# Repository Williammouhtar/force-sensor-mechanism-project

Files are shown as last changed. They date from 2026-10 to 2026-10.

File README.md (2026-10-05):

this project is meant to introduce flexure mechanisms through a force sensor project.
This project focuses mainly on translating user specifications into mechanical requirements in order to create a product that suits the user best.
such force sensors are used in industry by companies such as Hexagon for surface measurements as well as to recreate mechanical products into digital CAD
designs by taking multiple measurements on the entirety of the surface desired.

A detailed report is available in the Force-sensor-Rapport.pdf file.

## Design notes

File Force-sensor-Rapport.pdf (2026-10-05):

# Conception de Mécanisme : rapport

Marc Abou Jaoude, Oliver Abela, William El Mouhtar, Ziad Kriedieh,

## Tarek Hamad

### Projet de conception de mecanisme

Mai 2025

## Remerciements

Nous sommes reconnaissants envers Prof. Simon Henein pour avoir initialement mis en place ce projet et pour son soutien tout au long de son développement.

Nous tenons également à exprimer notre gratitude envers notre assistant principal, Prof. Florent Cosandier, dont le soutien continu a été d’une aide précieuse tout au long de ce projet.

De plus, nous souhaitons adresser nos remerciements les plus chaleureux à notre assistant secondaire, Alexandre Dao, pour ses conseils tout au long du semestre.

## Table des matières

1 Introduction | 3
2 Conception générale | 4
2.2 Schéma cinématique du corps d’épreuve représenté avec des articulations idéales . . . | 7
2.3 Calcul de la mobilité selon la méthode de Grübler et discussion des éventuels hyper-
3 Dimensionnement Détaillé | 8
3.5.1 | Calcul d’erreur pour une accélération en z due à la non-linéarité de l’équilibrage 20
4 Discussion | 24
5 Construction | 24
5.1 Argumentation des choix de construction (procédé d’usinage et assemblages, etc.) . . 24
6 Conclusion | 26
7 Annexes | 26

## 1 Introduction

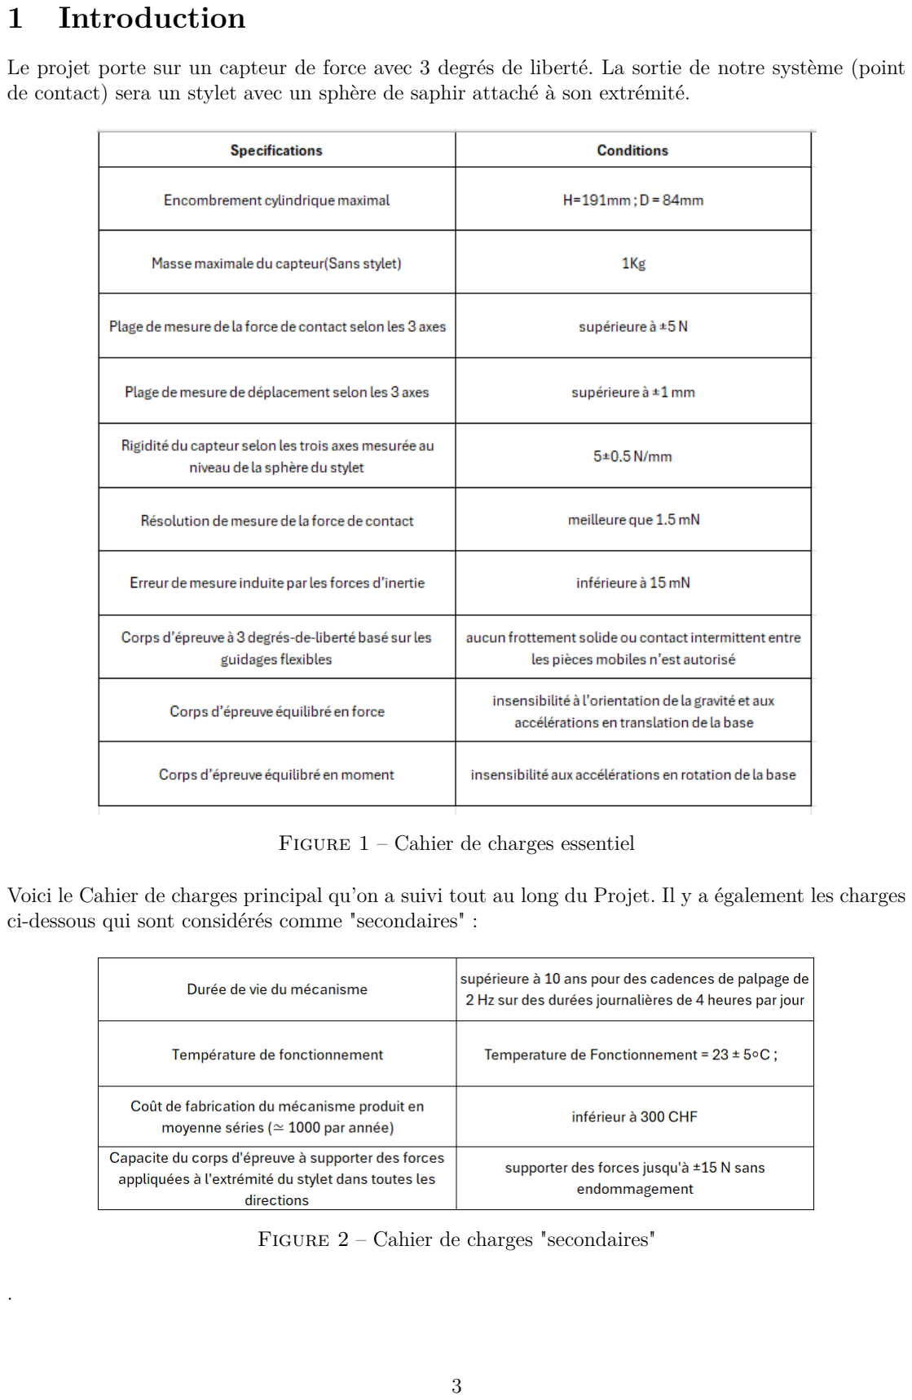
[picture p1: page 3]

Le projet porte sur un capteur de force avec 3 degrés de liberté. La sortie de notre système (point de contact) sera un stylet avec un sphère de saphir attaché à son extrémité.

Figure 1 – Cahier de charges essentiel

Voici le Cahier de charges principal qu’on a suivi tout au long du Projet. Il y a également les charges ci-dessous qui sont considérés comme "secondaires" :

Figure 2 – Cahier de charges "secondaires"

## 2 Conception générale

### 2.1 Explication du principe de fonctionnement

### 2.1.1 Principe de guidage du stylet à 3 degrés-de-liberté

Le système sera dans un cylindre de diamètre D = 84 mm et de hauteur H = 191 mm. Notre stylet aura les trois degrés de libertés suivantes : translations sur l’axe z, translation sur l’axe y et rotation sur l’axe x.

— Translation selon l’axe Z : ce mouvement sera guidé grâce aux deux lames de guidage L3 des deux côtés.
— Translation selon l’axe Y : ce mouvement sera guidé grâce aux quatre lames de base L1. Vu qu’on travaille sur de petits mouvements, on peut assumer que le mouvement selon l’axe de translation Y sera purement translationnel (donc on omet le mouvement parasite «Fp» de rotation).
— Rotation selon l’axe ry : ce mouvement sera guidé grâce aux deux lames de guidage L3 des deux côtés.

### 2.1.2 Principes d’équilibrage en force et en moment

Équilibrage en Force :

Le but fondamental de l’équilibrage en force est d’assurer l’insensibilité du système aux accélérations linéaires ne provenant pas d’une force appliquée sur le stylet. Par exemple, le simple fait de secouer le cylindre sur l’axe Z ne doit pas engendre la translation du stylet et donc du système ; Seul l’application d’une force sur ce dernier doit pouvoir engendrer un tel mouvement. Dans notre cas, on devra alors élaborer un système d’équilibrage en force sur les axes Z et Y.

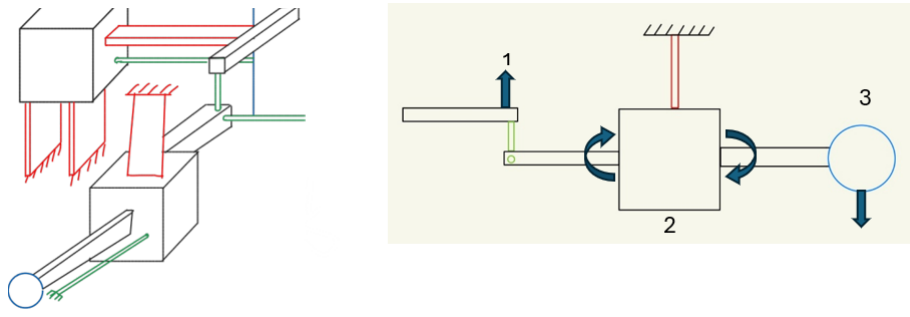
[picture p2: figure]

Figure 3 – Photo agrandie du systeme d’equilibrage en Force"

Considérons une force appliquée sur le stylet suivant l’axe Z. Cela va engendrer les étapes suivantes :

— 1- Translation de la tige t1.
— 2- rotation du bloc grâce à la lame L2
— 3- Rotation de la masse bleue dans la direction opposée à la translation du stylet.

Équilibrage en Moment :

Le but fondamental de l’équilibrage en moment est d’assurer l’insensibilité du système aux accélérations angulaires ne provenant pas d’une force appliquée sur le stylet. Par exemple, le simple fait de tourner le cylindre sur l’axe Y ne doit pas engendrer la rotation du système. Il faut équilibrer l’axe Y en moment vue que c’est le seul axe de rotation. Ceci sera simplement fait avec le meme systeme d’equilibrage que celui en force. Effectivement, la rotation par rapport à l’axe Y engendrera la rotation du bloc centrale qui à son tour mène à la flexion de la lame L2 et donc à la rotation des masses aux deux extrémités dans le sens inverse, annulant alors la rotation appliquée sur le cylindre.

### 2.1.3 Principe de mesure des déformations du corps d’épreuve

1. Le cahier des charges impose une plage de mesure de déplacement d’au moins ±1 mm. Cela élimine tous les capteurs dont la plage est inférieure à 2 mm. Ceci est cohérent avec le fait que l’on souhaite mesurer :

F = K · x avec K = 5 N/mm, ⇒ F = 5 · 2 = 10 N

Ce qui donne une plage totale de ±5 N, soit 10 N. Cependant, cette valeur est plutot limite car on ne prend pas K > 5.5 N/mm. les capteurs ayant une plage de déplacement < 3 mm peuvent être éliminés pour prendre un peu de marge.
2. Ceci limite le choix à 5 capteurs, répertoriés dans le tableau suivant :

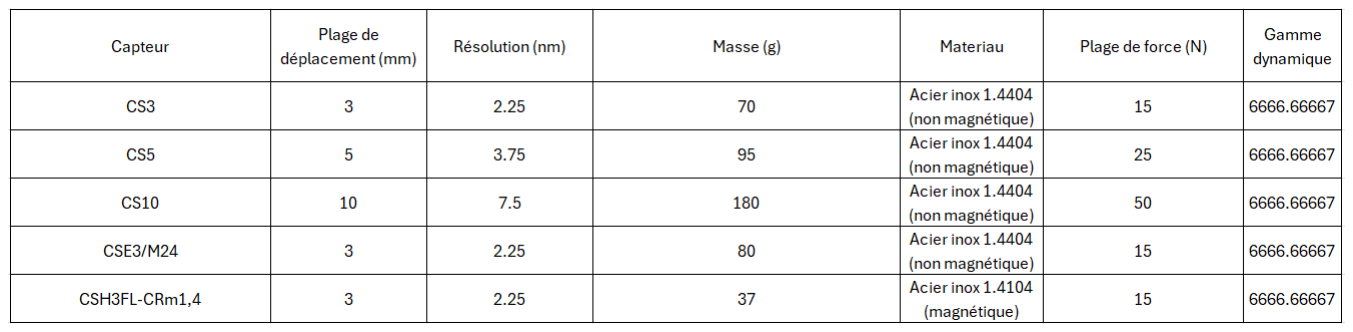
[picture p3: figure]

Figure 4 – spécifications des 5 capteurs restants

3. Le calcule de la gamme dynamique en déterminant la plage de mesure de force comme :

Plage force = K · plage déplacement, Gamme dynamique =

K · plage déplacement
résolution | =

5 · δ
ϵ

Or, tous les capteurs ont la même gamme dynamique, donc ce critère ne permet pas d’éliminer un des capteurs.
4. Enfin, le CS10 a une plage de mesure beaucoup trop grande par rapport à ce qui est nécessaire, ce qui n’est pas optimal.

Le CSH3FL-CRm1,4 se distingue par sa légèreté (70 g), ce qui est utile pour rester dans une masse mobile inférieure à 1 kg. De plus, il reste dans la plage minimale souhaitée, en force et en déplacement.La zone de mesure active, d’un diamètre de 10 mm, est largement suffisante pour garantir que les erreurs de déplacement du système n’affectent pas les mesures.

Il aurait également été possible d’utiliser le capteur CSE2, assez similaire au CSH3FL, avec une masse de 20 g, une zone de mesure active de 8 mm de diamètre et une gamme dynamique équivalente (6666,67). La seule caractéristique nécessitant une attention particulière aurait été sa hauteur de 22 mm, qui aurait pu poser des contraintes d’encombrement dans l’intégration du système.

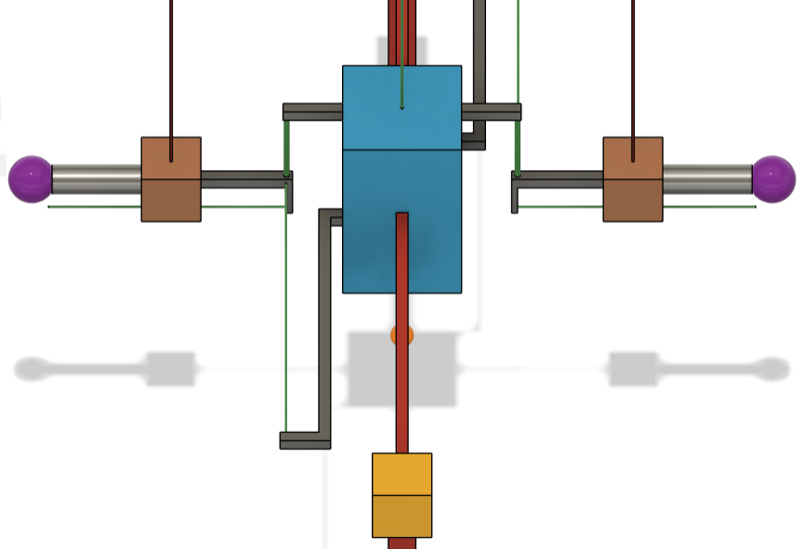
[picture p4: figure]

Figure 5 – Emplacement des capteurs

Comme il peut être observé dans le dessin, deux capteurs sont montés sur les blocs marron : la partie fixe est fixée à la tige et la partie mobile est fixée au bloc. Cet emplacement des capteurs est jugé stratégique.

En effet, lors d’une translation selon l’axe z, il est constaté que les deux plaques mobiles restent à la même hauteur. Lors d’une rotation selon l’axe y, il est constaté que l’une des plaques s’élève tandis que l’autre s’abaisse, selon le sens de rotation. Le troisième capteur peut enfin être positionné sur l’un des côtés droit ou gauche du bloc bleu.

Pour distinguer entre une translation selon l’axe z et une rotation ry lors d’une mesure, il est possible de programmer les capteurs en conséquence.

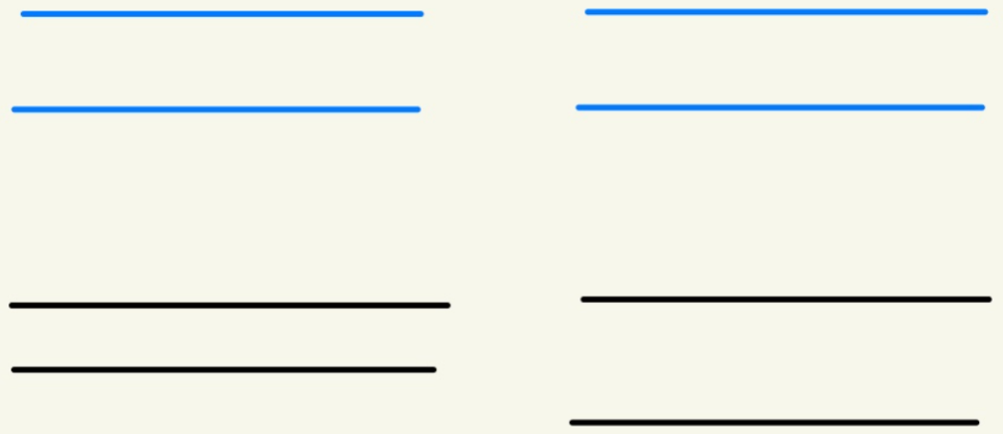
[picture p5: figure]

Figure 6 – etat des capteurs en translation (bleu) vs en rotation (noir)

### 2.1.4 Mise en évidence des concepts originaux

Pour l’implémentation des capteurs, il est favorable de programmer les 2 capteurs des deux côtés de la manière suivante :

— captor_1 étant la distance entre la plaque mobile et fixe du capteur à gauche
— captor_2 étant la distance entre la plaque mobile et fixe du capteur à droite

En prenant les erreurs de mesures induites par les forces d’inertie à 15 mN et un Keq = 4,5, on obtient :

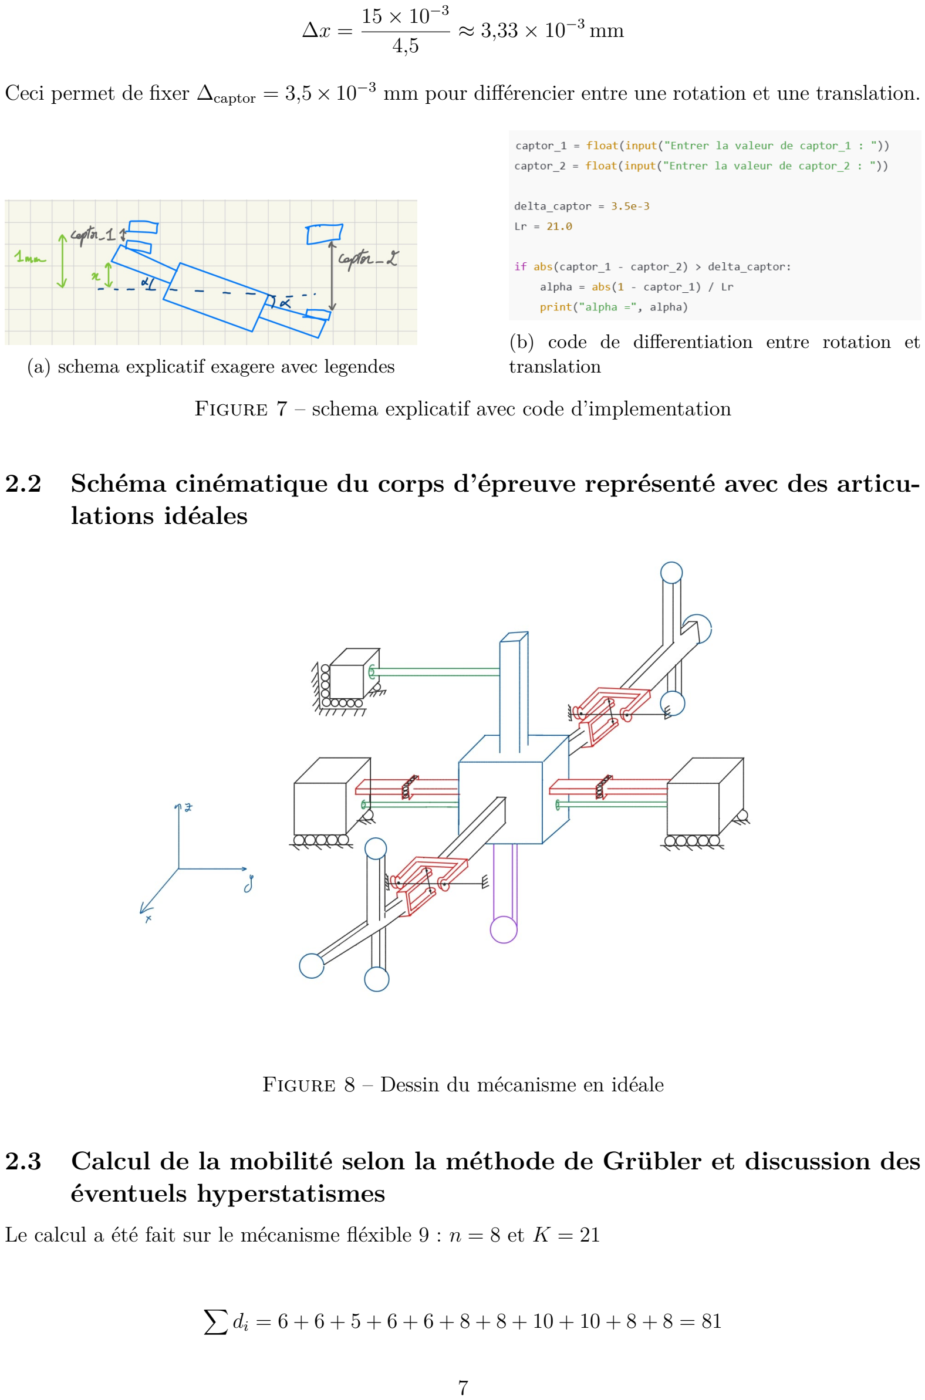
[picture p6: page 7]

∆x =

15 × 10⁻³
4,5

≈ 3,33 × 10⁻³ mm

Ceci permet de fixer ∆captor = 3,5 × 10⁻³ mm pour différencier entre une rotation et une translation.

(a) schema explicatif exagere avec legendes
(b) code de differentiation entre rotation et translation

Figure 7 – schema explicatif avec code d’implementation

### 2.2 Schéma cinématique du corps d’épreuve représenté avec des articulations idéales

Figure 8 – Dessin du mécanisme en idéale

### 2.3 Calcul de la mobilité selon la méthode de Grübler et discussion des éventuels hyperstatismes

Le calcul a été fait sur le mécanisme fléxible 9 : n = 8 et K = 21

Xdi = 6 + 6 + 5 + 6 + 6 + 8 + 8 + 10 + 10 + 8 + 8 = 81 b = K − n + 1 = 21 − 8 + 1 = 14

M =

Xdi − 6b = 81 − 6 · 14 = 81 − 84 = −3

Le DOF (degree of freedom) étant égal à 3, le DOH (degré d’hyperstaticité) sera :

DOH = DOF − M = 3 − (−3) = 3 + 3 = 6

Ces degrés d’hyperstatisme peuvent être expliqués par : — les deux tiges t3 en parallèle avec l3,
— les deux lames l1 en parallèle de chaque côté,
— la présence des deux lames l5 en parallèle,
— ainsi que les deux lames l4.
Donnant effectivement un DOH = 6.

### 2.4 Implémentation de la cinématique du corps d’épreuve en guidages flexibles

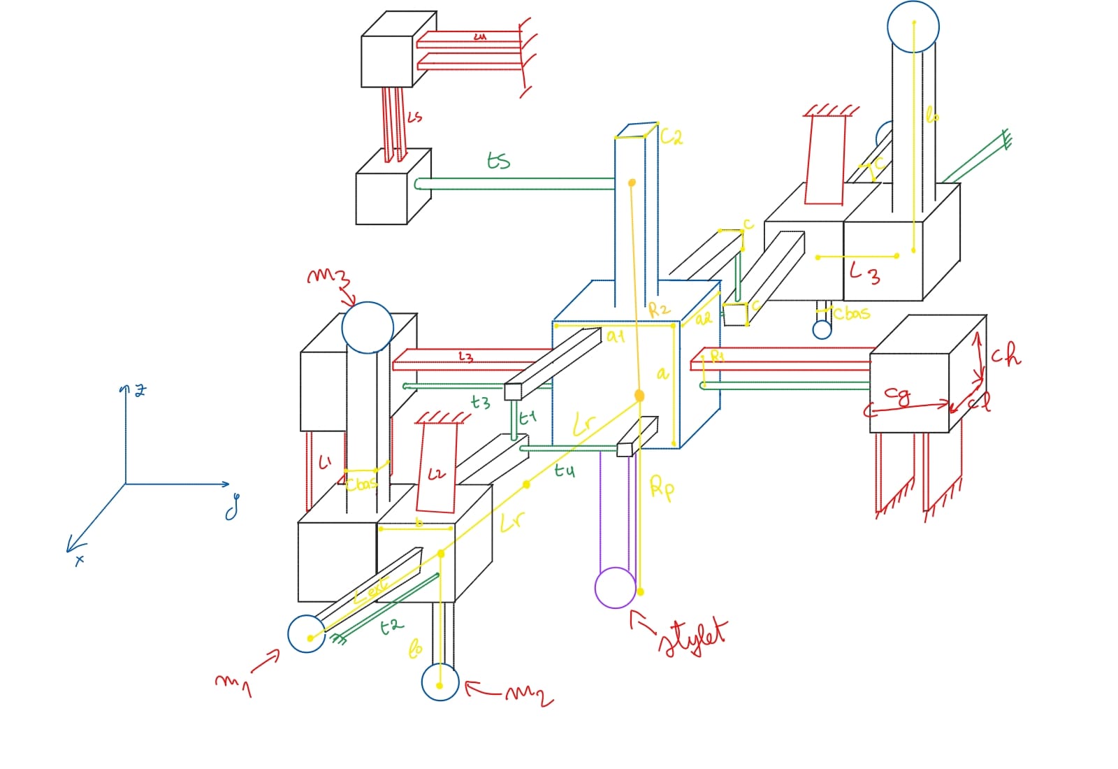
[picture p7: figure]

Figure 9 – Dessin du mécanisme

## 3 Dimensionnement Détaillé

### 3.1 Calcul de la Rigidité Equivalente

Le schéma suivant montre le nom donné à chaque élément fléxible pour faciliter les notations dans le calcul.

Le cahier des charges impose un Keq entre 4,5 et 5,5 N/mm pour chaque degré de liberté, ainsi qu’une course de 1 mm. Sachant que la course de la majorité des éléments peut être facilement déterminée, le Keq a été déterminé en égalisant les énergies de déformation de ces éléments avec la formule suivante :

1
2
- Keq · x

2 =

XÉnergie de déformation

Dans la suite de cette section le KαM a été inspiré par le cas mentionné dans la thèse du Prof. Simon Henein : « Conception des structures articulées à guidages flexibles de haute précision » page 209. Voir l’image ci-dessous :

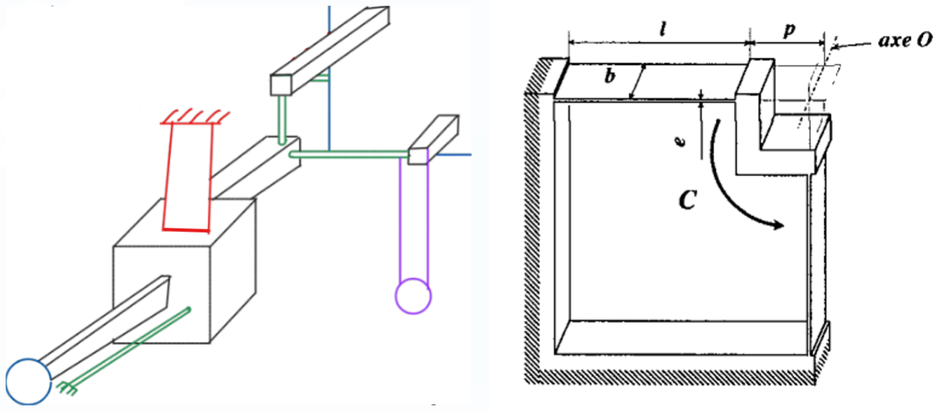
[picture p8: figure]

Figure 10 – Comparaison de notre systeme (gauche) avec le cas de la These du Prof. Henein (droite)

La formule de rigidité utilisée est donc : KαM =

8EI(b

2+3pb+3p

2
)
b

3

. Contrairement au cas de charge de la thèse, le mécanisme est guidé par une lame et une tige, KαM représente donc la ridigité de chacun de ces deux éléments :

KαM,i =

4EIy,i(l

2
i + 3pli + 3p

2
)
l

3
i
avec p etant la longeur du bloque et i = L2,t2

Le E et G representent le module de Young et de cisaillement du Titane (voir la raison du choix de materiel dans la partie 5.2)

Pour les KfP,ij (i = lame, tige et j = 1, 2, 3, 4, 5), on a également utilisé la formule (p190 cas de charge c) de la thèse du Prof. Simon Henein suivante :

KfP,ij =

12EIy,ij
l

3

et finalement pour les Ktors,ij (j = lame, tige et i=1, 2, 3, 4, 5), la fonction qu’on a suivi est la suivante :

Ktors,ij =

GIy,ij
l
Remarque : la tige t5 et les deux lames L4 mise en parallèle sont bien en série car la deformation ∆z n’est pas forcément la même.

Lors du déplacements du stylet d’une distance ∆z , les déformations suivantes ont lieu :
— Flexion causée par une déformation ∆z des deux lame L3, des deux tige t3 ainsi que de la mise en série de la tige t5 et des deux lames L4.

— Flexion des deux L2 et des deux t2 causé par un angle θ = arcsin
∆z
Lr
— Torsion des deux t4 de ce même angle θ.
Les flexions parasites des tige t1 et des lames L1 ont été négligée, le calcul a été fait plus bas. La formule de la conservation de l’énergie devient alors :

1
2

Keq,z ·z

2 = KfP,L3 ·z

2+KfP,t3 ·z

2+

1
2

2KfP,L4 · KfP,t5

2KfP,L4 + KfP,t5

!
z

2+KαM,L2 ·θ

2+KαM,t2 ·θ

2+Ktors,t4 ·θ

2
(1)

Sachant que ∆z << Lr, θ = arcsin
∆z
Lr
≈

∆z
Lr

et l’expression (2) suivante est obtenue :

Keq,z = 2 · (KfP,L3 + KfP,t3 +

KfP,L4 · KfP,t5

2KfP,L4 + KfP,t5

+

KαM,L2 + KαM,t2 + Ktors,t4
L²
r
) | (2)

Lors du déplacement du stylet d’une distance ∆y, les déformations suivantes ont lieu :
— Flexion causée par une déformation ∆y des quatre lames L1 et des deux lames L5. — Flexion des deux L2 et des deux t2 causée par un angle θ = arcsin
∆y
Lr
— Torsion des deux t1 de ce même angle θ.
Les flexions parasites des tige t1 et des lames L1 ont été négligée, le calcul a été fait plus bas. La formule de la conservation de l’énergie devient alors :

1
2
- Keq,y · ∆y

2 = (2 · KfP,L1 + KfP,L5) ∆y

2 + (Ktors,t1 + KαM,L2 + KαM,t2) θ

2 | (3)

Sachant que ∆y << Lr, θ = arcsin
∆y
Lr
≈

∆y
Lr

et l’expression (2) suivante est obtenue :

Keq,y = 2 ·
2KfP,L1 + KfP,L5 +

Ktors,t1 + KαM,L2 + KαM,t2
(Lr)
2

!
(4)

Les flexions parasites des tiges et des lames concernées sont induites par un déplacement parasite résultant d’une violation de l’hypothèse selon laquelle la longueur de ces éléments reste constante durant le mouvement. Le deplacement parasite et les contributions parasites valent :

— ∆xparasite = Lr − Lr · cos

arcsin
∆z
Lr

et Kz parasite,t1 = KfP,t1 · 2Lr ·

1−cos(arcsin(
∆z
Lr

))

∆z

2
≈
4,88 N/m

— ∆yparasite = LL3 −

q
L

2
L3 − ∆z

2 et Kz parasite,L1 = 4 ·

∆y
∆z

2
- KfP,L1 ≈ 0.891N/m

— ∆xparasite = Lr − Lr · cos

arcsin
∆y
Lr

et Ky parasite,t4 = 2 ·

Lr·(1−cos(arcsin( ∆y
Lr

))
∆y

2
- KfP,t4 ≈
11 N/m
Lors de la rotation du stylet autour de l’axe y, équivalente à un déplacement ∆x du bout du stylet (avec θ = arcsin
∆x
Rp
, Rp étant la distance entre le centre du bloc principal et l’extrémité du stylet), les déformations suivantes ont lieu :
— Flexion des deux lames L2 et des deux tiges t2 selon un angle θ.
— Torsion des deux tiges t4 selon un angle 2θ.
— Torsion des deux tiges t3, des deux lames L3 et de la tige t5 selon un angle θ.
— Flexion des tiges t3 provoquée par un déplacement égal à R1 · θ, où R1 est la distance entre l’axe de la tige et celui de la lame L3 (centrée sur le bloc principal).
— Flexion de la tige t5 induite par un déplacement égal à R2 · θ, avec R2 la distance entre le centre de la tige t5 et le centre du bloc principal.
Pour avoir les bonnes dimensions de N/m, le Keq,ry a été divisé par Rp. La formule de la conservation de l’énergie devient alors :

1
Keq,ry · θ

2 =

1
2 · (Ktors,L3 + Ktors,t3 + R

2
1
- KfP,t3 + Ktors,t4 · 4

+ KαM,L2 + KαM,t2) + Ktors,t5 + KfP,t5 · R

2/2
- θ

/Rp

(5)

Sachant que ∆x ≪ Rp, on a θ = arcsin
∆x
Rp
≈

∆x
Rp

, et l’expression suivante est obtenue :

Keq,ry = 2·(Ktors,L3+Ktors,t3+KfP,t3 ·R

2
1+4·Ktors,t4+KαM,L2+KαM,t2+Ktors,t5+KfP,t5 ·R

2/2)/Rp

2
(6)

L’ensemble des formules permettant de calculer les rigidités équivalentes selon les directions z, y et ry a été implémenté dans un programme Python, qui a permis de générer les histogrammes présentés en figure 11. Ces histogrammes représentent la contribution de chaque élément flexible à la raideur totale dans chaque direction. En complément, les graphiques des contraintes maximales 12 dans chaque élément ont également été utilisés pour évaluer la faisabilité mécanique de la conception. Ces outils ont permis de mener un tâtonnement efficace pour obtenir les dimensions 1 des éléments flexibles respectant les exigences du cahier des charges. Les rigidités obtenues sont les suivantes : Keq,z = 4944,00 N/m, Keq,y = 5234,31 N/m et Keq,ry = 4926,01 N/m, toutes conformes aux spécifications imposées.

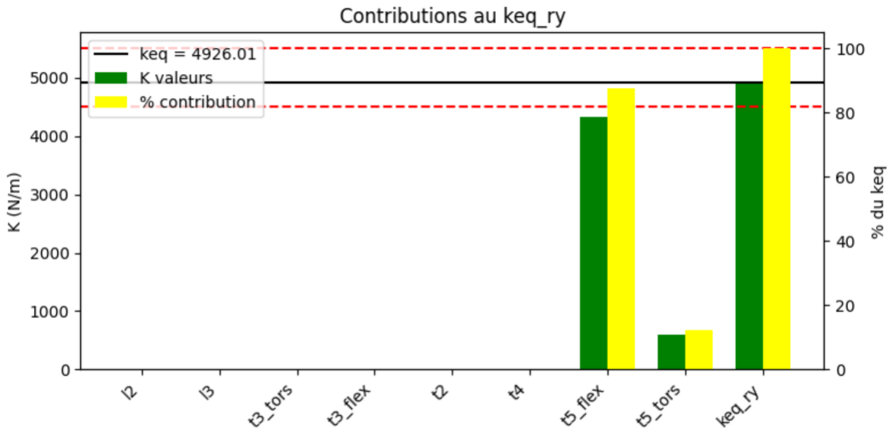
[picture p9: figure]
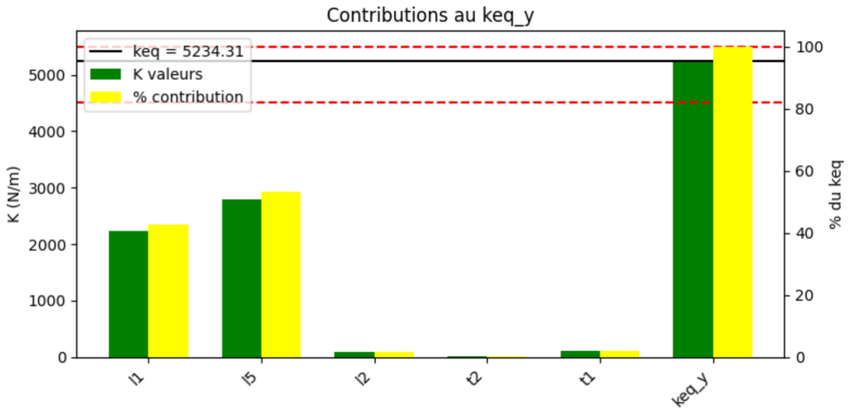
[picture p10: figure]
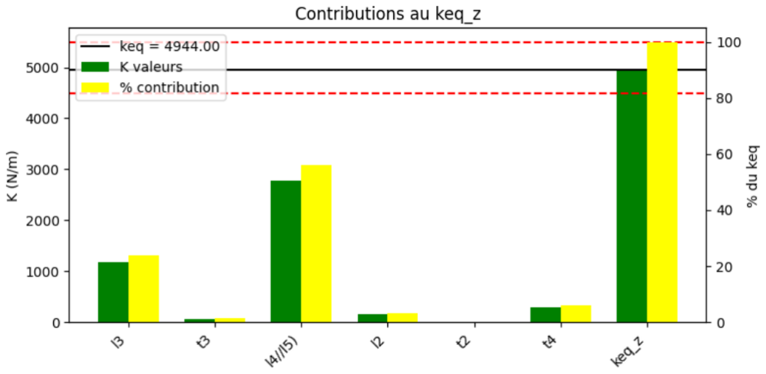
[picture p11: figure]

Figure 11 – Histogrammes de la contribution de chaque élément flexible à la rigidité équivalente dans les trois degrés de liberté : z, y et ry.

Comme le montre le graphique11, les éléments flexibles autres que la tige t5 ont une contribution très faible pour la rigidité face à la rotation. Ceci est du au fait que le bras de levier Rp, permettant la rotation du système atour de l’axe y, est tres important réduisant ainsi la rigidité du système pour ce mouvement là : intuitivement le long bras de levier fait quon a besoin d’un petit deplacement du bout du stylo et donc de très peu d’énergie pour réalisé la rotation. C’est pour cette raison la que le mecanisme du haut qui inclu la tige t5, les lames L4 et les lames L5 a été intorduit pour augmenter la rigidité du système pour cette rotation.

### 3.2 Calcul des Contraintes

Comme mentionné précédemment, le matériau choisi est le titane, qui supporte une contrainte maximale de 500 MPa. Dans le cahier des charges, le mécanisme est censé résister à une charge pouvant atteindre 15 N et la rigidité du système dans chaque direction est de l’ordre de 5000 N/m. Dans l’hypothèse des petits mouvements et de la linéarité des déformations des corps flexibles, pour un déplacement de 1 mm (force d’environ 5 N), la contrainte ne doit pas dépasser 500
3 MPa
≈ 166,67 MPa. Les contraintes ont été calculées à partir de la course et en fonction du type de déformation de l’élément fléxible, les formules ont été tirées de la thèse du Prof. Heinein (p.189-195).

Pour les tiges :
— Torsion : σ =

√
3·G·dt·θtorsion
2lt
— Flexion due à un moment : σ =

E·(2dt·lt+3dt·p)·θf lexion
l

2
t

(formule tirée de la thèse du Prof. Henein, cas illustré en figure 10) — Flexion due à une force : σ =

3·E·dt·∆x
l

2
t
Pour les lames :
— Torsion : σ =

√
3·G·hL·θtorsion
lL
— Flexion due à un moment : σ =

E·(2hL·lL+3hL·p)·θf lexion
l
L

(formule tirée de la thèse du Prof. Henein, cas illustré en figure 10)

— Flexion due à une force : σ =

3·E·ht·∆x
l
L

. C’est la formule du cas de charge c (p.190) qui a été choisie pour la similarité de la cinématique des lames encastrés qui subissent une flexion en force.
Les éléments suivants sont sollicités lors d’un déplacement ∆z :
— L3, L4 et t3 sont en flexion sous l’effet d’une force avec une course ∆z.
— L2 et t2 sont en flexion sous l’effet d’un angle θ = arcsin
∆z
Lr
— t4 est en torsion selon un angle θ = arcsin
∆z
Lr
— t1 est en compression, due au moment de rappel généré par la lame L2 et la tige t2 :

σcompression,t1 =

(KαM,t2 + KαM,L2) · arcsin ∆z
Lr

Lr ·

πd²
t1
4

— L1 est en compression, due à la force de rappel des tiges L3 et t3 sur chacune des deux lames L1 :

σcompression,L1 =

(KfP,L3 + KfP,t3) · ∆z

2 · bL1 · hL1
— L5 est en compression, due à la force de réaction de la mise en série des deux lames L4 et de la tige t5 :

σcompression,L5 =

2KfP,L4 · KfP,t5

2KfP,L4 + KfP,t5

·

∆z

2 · bL5 · hL5

Lors d’un déplacement ∆y, les déformations suivantes ont lieu :
— Torsion de la tige t1 et de la lame L2 selon un angle θ = arcsin
∆y
Lr
— Flexion de la tige t2 selon un angle θ = arcsin
∆y
Lr
— Flexion des lames L1 et L5 due à un déplacement ∆y.
— Compression de la tige t3 et de la lame L3 sous l’effet de la force de rappel des lames L1 :

σcompression,t3 =

8KfP,L1 · ∆y
π · d

2
t3

, σcompression,L3 =

2KfP,L1 · ∆y

bL3 · hL3

— Compression de la tige t5 et des lames L4 sous l’effet de la force de rappel des lames L5 :

σcompression,t5 =

8KfP,L5 · ∆y
π · d

2
t5

, σcompression,L4 =

KfP,L5 · ∆y

bL4 · hL4

— Compression de la tige t4 due à la force de rappel combinée de la torsion de L2 et de la flexion de t2 :

σcompression,t4 =

4 · (Ktors,L2 + KαM,t2) · ∆y
π · d
| 2 t4
- Lr
Lors de la rotation autour de l’axe y les éléments suivants sont solicités : — Torsion des lames L3, des tiges t3 et t5 selon un angle θ = arcsin
∆x
Rp
— Torsion des tiges t4 selon un angle 2θ.
— Flexion due à une force appliquée sur les tiges t3 et t5, calculée à partir des déplacements R1 ·θ et R2 · θ respectivement.
— Flexion due à un moment pour la lame L2 et la tige t2, selon un angle θ.
— Compression de t1 due à la force de rappel générée par la flexion en moment de L2 et t2 :

σcompression,t1 =

KαM,L2 + KαM,t2

Lr · At1

- α

— Traction de L1 due à la force de rappel générée par la torsion de L3 et la flexion de t3 :

σtraction,L1 =

3 · (Ktors,L3 · α + KfP,t3 · R²
- α)
hL1 · b
L1

La contrainte dans les lames L4 et L5 sont ceux du cas de figure h de la page 190 de la thèse du Prof. Henein. Ce mouvement est causé par la force de rappele de la tige t5. Comme ce mouvement a été considéré impossible durant le cours, la constante de rigidité de la lame est appelé Kinterdit

σ =

3Eb
l

2

- ∆x =

3Eb
l

2

·

Frappel,t5

Kinterdit

=

3Eb
l

2

·

KfP,t5 · R2 · θ
12E · hb³

=

l · KfP,t5 · R2 · θ
4hb²

(7)

Toutes ces contraintes ont été calculées pour un déplacement de 1 mm du stylet dans un programme Python afin de générer les histogrammes suivants. Les éléments ont été dimensionnés de telle sorte que la contrainte reste toujours inférieure à la contrainte limite comme montre l’histogramme. Le système est donc capable de résister à une force de 15 N.

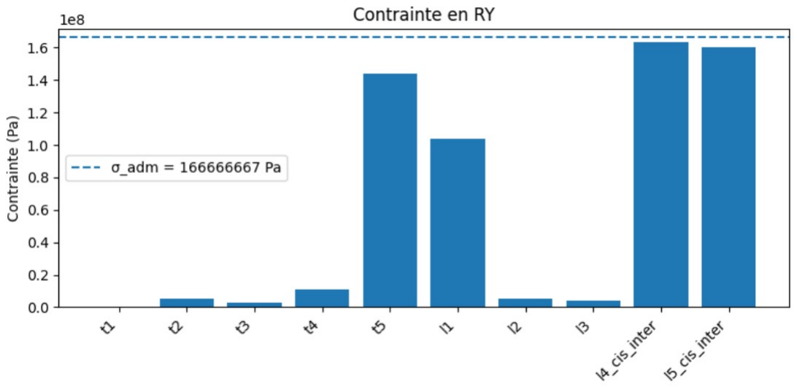
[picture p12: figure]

Figure 12 – Contraintes maximales dans les éléments pour un déplacement de 1 mm du stylet selon les trois degrés de liberté.

Finalement les dimensions qui verifient toutes les contraintes du cahier des charges sont les suivants :

Table 1 – Dimensions obtenues pour les lames et les tiges du mécanisme

Lames | Longueur (mm) | Épaisseur h (mm) | Largeur b (mm)
L1 L2 L3 L4 L5 | 40 40 25 32 25 | 0,5 0,2 0,3 0,36 0,28 | 2,5 1,0 3,0 8,6 8,7
Tiges | Longueur (mm) | Diamètre d (mm)
t1 t2 t3 t4 t5 | 10 27 25 15 32 | 0,3 0,121 0,3 0,5 3,9

Matériau utilisé : titane E = 114 GPa et G = 41 GPa ; En mm : Lr = 7.5, R1 = 1, R2 = 21, Rp = 22 et b = 6

### 3.3 Vérification Flambage

Pour l’axe z :
— t1 : rappel de t2 et l2 qui sont en flexion selon un moment ;
— l1 : rappel de l3 et t3, flexion selon une force ;
— l5 : rappel de la mise en série de t5 avec les deux l4 en parallèle.

Pour l’axe y :

— t3 : rappel de l1 en flexion selon une force ;
— t4 : rappel de l2 en torsion et de t2 en flexion selon un moment ; — t5 : force de rappel de la lame l5 mise en flexion ;
— l3 : force de rappel des deux lames l1 mises en flexion ;
— l4 : force de rappel des deux lames l5 mises en flexion .

Mouvement ry :
— tige 1 mise en compression par la force de rappel causée par l2 et t2 (flexion par un moment).

Pour la force critique Fcr, le mode fondamental n = 1 est considéré et la longueur efficace est donnée par Leff =

L
2

, en prenant le cas d’une poutre encastrée aux deux extrémités, comme expliqué dans le cours de CdM 1 (pdf – semaine 10 – Flambage, slide 22). Les formules des contraintes de compression et de la contrainte critiquede flambage ont éétéiimplémentéess dans un programme Python qui donne leshistogrammes suivant 13. Aucun flambage ne devrait se produire dans le système. Le seul cas qui pourrait s’en approcher est celui de la tige t3. Cela s’explique par le fait que le cas extrême a été considéré, dans lequel la force de rappel n’est pas répartie entre la lame l3 et la tige t3, mais est supposée entièrement appliquée sur la tige.

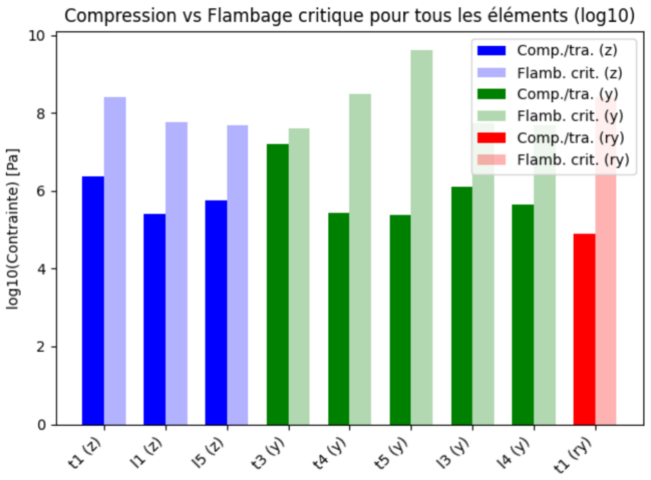
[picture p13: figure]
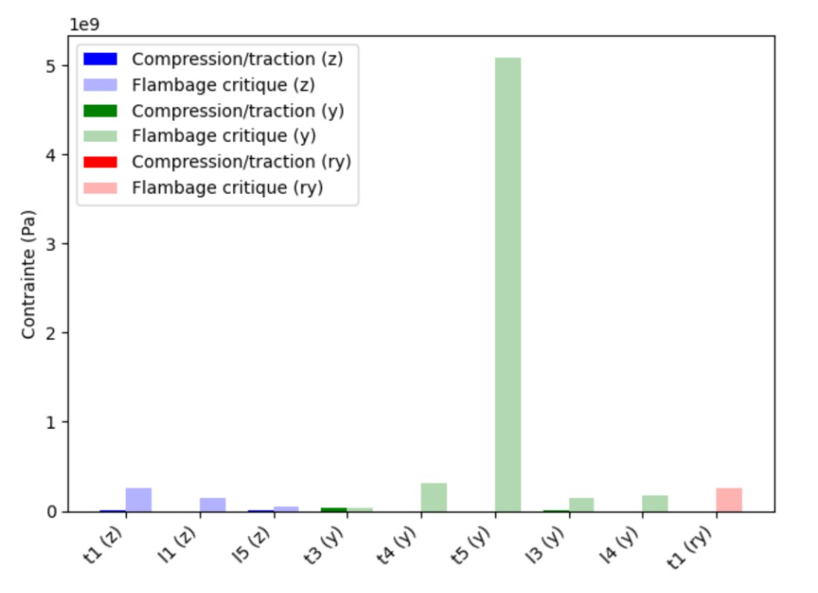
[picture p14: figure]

(a) Échelle linéaire | (b) Échelle log 10

Figure 13 – Comparaison de la force critique de flambage vs force de compression exercée sur les éléments. Pour des soucis de visualisation, le logarithme des valeurs a été pris

### 3.4 Equilibrage en Force et en Moment

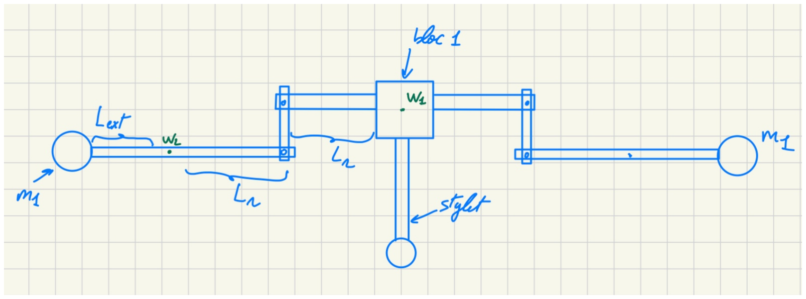
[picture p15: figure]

Figure 14 – Schéma pour l’équilibrage en force

Dans l’ancienne solution présentée au rendu 1, pour avoir un équilibrage en force selon l’axe z et y (il s’agit de la situation mécanique), on impose :

Xmivi = 0

(avec Lext = Lr donc les vitesses sont égales)

2mboule − (mbloc + mstylet) = 0 | ⇒ | 2 · mboule = mbloc + mstylet | (1)

Pour un équilibrage en moment autour de ry : (moments cinetique egaux)

(Ibloc + Istylet)ωW1 = 2 · Iboule · ωW2

(2)

où W1 et W2 sont des points définis dans le schéma.

Problème 1 : Vu que Lr ≪ longueur du stylet, l’équilibrage en moment ne serait pas correct selon l’équation (1). En gardant la même distance Lr, il faudrait augmenter le moment cinétique des boules autour de W2, tout en conservant l’équilibrage en force.

Solution 1 : Ajouter des masses afin d’augmenter l’inertie du système et ainsi ajuster l’équilibrage en moment, sans interférer avec l’équilibrage en force. L’ajout de masses au-dessus et en dessous du cardan, selon l’axe vertical, est la solution implémentée.

Probleme 2 : Pour une accélération en x, les 2 boules horizontales ne jouent pas de rôle pour l’équilibrage. Une accélération en x génère un moment suivant ± eˆy donné par :

M = mstylet ×

L
3

+

a
2
- ax | (8)

(masse * distance du centre de masse par rapport au centre de rotation * accélération).

Solution 2 : Pour cela, les boules situées au-dessus et en dessous du cardan doivent avoir une différence de masse, de manière à générer, sous l’effet de l’accélération, un moment qui s’oppose à celui imposé par la tige. Cette opposition permet de rétablir l’équilibre en moment. L’ajustement se fait donc en imposant volontairement une différence de masse entre les deux boules, tout en conservant une position symétrique pour ne pas perturber l’équilibrage en force.

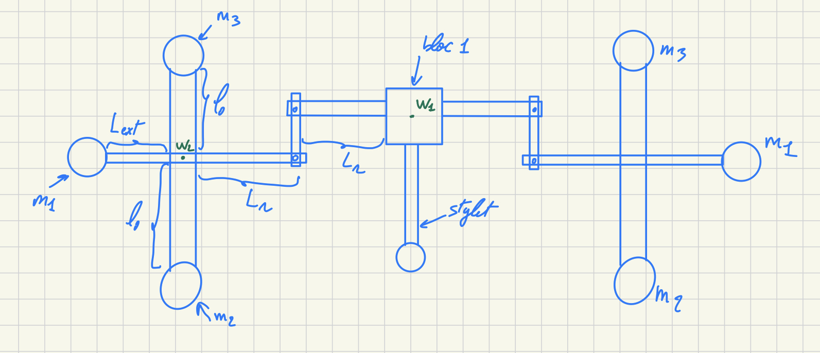
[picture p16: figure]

Figure 15 – Schéma de la solution d’équilibrage proposée

Moment généré par le stylet :

Mstylet = mstylet ×

L
+

a
× ax

Pour une translation selon z : Le changement du centre de masse m2 et m3 est négligeable vu que les masses sont montées verticalement. Leurs mouvements suivent la forme d’un sinus autour de −

π
2

:

(sin(x))′ = cos(x) ⇒ cos −

π
2
= 0 | ⇒ | la variation est bien minimale.

Pour une translation en y : Les masses m2 et m3 tournent autour d’elles-mêmes, et donc n’affectent pas la variation de la position du centre de masse.

Pour l’équilibrage en force selon z : En négligeant les masses m3 et m2, on applique le principe de conservation de la quantité de mouvement :

2 · m1 · v1 = (mstylet + mbloc) · v2

avec v1 =

Lext
Lr
- v2.

On obtient donc :

m1 =

(mstylet + mbloc) · Lr

2 · Lext

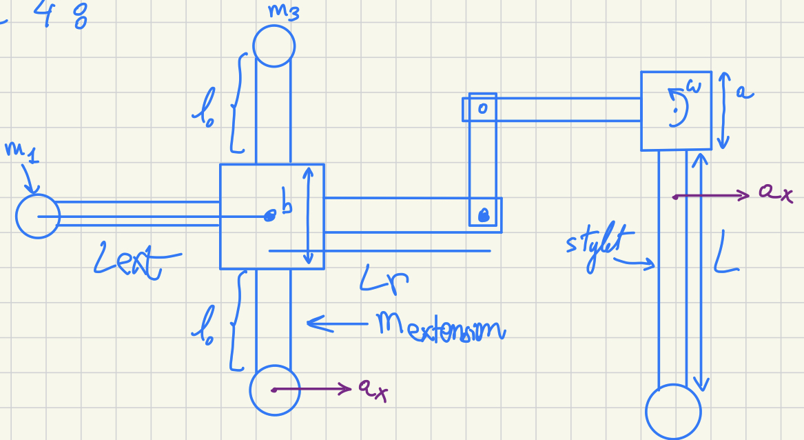
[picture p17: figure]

Figure 16 – Schéma du moment induit par une accélération en x

### 3.4.1 Stabilité du système selon l’axe x

Pour que le système soit stable selon x, il faut que le moment généré par les deux masses placées au-dessus (m2) et en dessous (m3) du cardan soit égal à celui généré par le stylet.

### Calcul du moment généré par les masses m2 et m3 (et leurs extensions)

Le moment total est donné par :

Moment = masse totale × position du centre de masse × ax

Pour la masse supérieure m2 avec son extension mext, on a :

(m2 + mext) · ax ·

m2·l0+mext·((l0− b
)/2+ b

2 )
m2+mext |

= M2

De même, pour la masse inférieure m3 :

(m3 + mext) · ax ·

m3·l0+mext·((l0− b
2

)/2+ b

2 )
m3+mext |

= M3

La différence entre les deux moments est donc :

∆M = ax · l0 · (m2 − m3)

### Égalisation avec le moment du stylet

Le moment généré par le stylet est donné par :

Mstylet = mstylet · ax ·

L
3

+

a
2

En égalant les deux moments :

2 · ax · l0 · (m2 − m3) = mstylet · ax ·

L
3

+

a
2

On peut simplifier par ax (supposé non nul), ce qui donne :

m2 − m3 =

mstylet
2l0

L
3

+

a
2

Ce résultat donne la différence de masse à imposer entre m2 et m3 pour garantir la stabilité en moment selon l’axe x.

### 3.4.2 Calcul des masses m2 et m3, equilibrage en moment

Pour équilibrer le système en moment, on n’a qu’à égaliser les moments cinétiques selon y.

Le centre de masse du stylet étant situé à un tiers de sa longueur depuis son extrémité inférieure, cela indique une répartition de masse plus importante vers un côté, c’est-à-dire une densité linéique non uniforme et croissante vers la base.

Par comparaison :

— Une tige homogène de longueur L a son centre de masse au milieu et un moment d’inertie (par rapport à son centre de masse) donné par :

IG =

1
12

ML² ≈ 0,083 ML²

— Dans notre cas, le centre de masse est situé à xG =

L
3

, ce qui implique que la masse est plus excentrée.

Ainsi, on peut raisonnablement approximer l’inertie du stylet par :

IG ≈

1
9

ML² ≈ 0,111 ML²

Cette valeur est légèrement supérieure à celle d’une tige uniforme, ce qui est cohérent avec une masse répartie plus loin du centre.

Densités massiques utilisées :

ρ1 : masse volumique du bâtiment
ρ2 : masse volumique du côté extérieur
ρ3 : masse volumique en dessous du cardan
ρ4 : masse volumique de la boule au-dessus du cardan

Masse du bloc central :

mblocc = ρ1

aa1a2 + 4c

2

lr −

a2
2
+ c

2/2
r2 −

a
2

Inertie du stylet (axe y) :

Istylet,y =

1
9

mstyletl

2
tige + mstylet

ltige
3

+

a
2

!2

Masse delta boule basse :

∆mboule =

mstylet
2

·

ltige
3 +

a
2
lo

Inertie du bloc central (axe y) :

Iblocc,y =

1
12

ρ1aa1a2(a

2 + a
2/2)

+ 4

1
12

ρ1c

2

lr −

a2
2

3
+ ρ1c

2

lr −

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
r2 −

a
2

3
+ ρ1c

2/2
r2 −

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
Masse du bloc cardan :

Mcardan = ρ1c

2
lr −

b
2

!
+ 2ρ1c

2
bas

lo −

b
2

!
+ ρ1c

2
lext −

b
2

!
+ ρ1b

3

Inertie du bloc cardan (axe z) :

Icardan,z =

1
6

ρ1b

5

+

1
12

Mext2

lr −

b
2

!2
+ Mext2

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
baslo · 2

+ L

2/3· ρ1c

2
baslo

+

1
12

Mext2

lext −

b
2

!2
+ Mext22

lext
2

+

b
4

!2

Inertie du bloc cardan (axe y) :

Icardan,y =

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
lr −

b
2

!3
+ ρ1c

2
lr −

b
2

! lr
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
lo −

b
2

!3
+ ρ1c

2
bas

lo −

b
2

! lo
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
lext −

b
2

!3
+ ρ1c

2
lext −

b
2

! lext
2

+

b
4

!2

Inerties des boules selon y :

Iext,y =

2
5

m

5/3
1

3
4πρ3

!2/3
+ m1l

2
ext

Ibas,y =

2
5

m⁵/3

3
4πρ4

!2/3
+ ml²
o

Ihaut,y =

2
5

(m − ∆mboule)

5/3

3
4πρ4

!2/3
+ (m − ∆mboule)l

2
o

Équation à résoudre pour egaliser les moments cinetiques :

Iext,y + Ibas,y + Ihaut,y =

Istylet,y + Ibloc central,y − 2Ibloc cardan, y
2

Valeurs numériques obtenues : les notations sont inscrits sur le schéma.9

Mbloc central = 0.0161006 kg
Istylet,y = 0.00100945 kg · m²

Ibloc central,y = 9.2056 × 10⁻⁷ kg · m²
Mbloc cardan = 0.0185592 kg Icardan,y = 6.5950 × 10⁻⁶ kg · m² Icardan,z = 1.868048 × 10⁻⁵ kg · m² m1 = 0.02902515 kg
Iext,y = 7.6223 × 10⁻⁶ kg · m²
m2 = 0.25635 kg
Ibas,y = 3.2036 × 10⁻⁴ kg · m² m3 = 0.14246 kg
Ihaut,y = 1.7061 × 10⁻⁴ kg · m²

Im1,z = Im1,y

Im2,z =

2
5m2R²

2 = 4.096 × 10⁻⁵ kg · m²

Im3,z =

2
5m3R²
3 + m3l

2

3 = 2.45 × 10⁻⁵ kg · m²
Rbas = 0.02004 m, | Rhaut = 0.01648 m, | Rext = 0.00970 m

Paramètres utilisés (ligne par ligne) :

ρ1 = 7600 kg/m

(matériau des blocs)
ρ2 = 7600 kg/m

(boule intérieure)
ρ3 = 9000 kg/m

3
(boule extérieure, cuivre) ρ4 = 7600 kg/m

3
(boule au-dessus du cardan)
a = 17 mm | (côté du bloc central)
a1 = 17 mm | (autre côté du bloc)
a2 = 6 mm | (hauteur du bloc)
c = 2 mm | (largeur des extensions)
b = 6 mm | (côté des blocs cardan)
c2 = 5 mm | (largeur du bloc arrière)
lr = 7.5 mm | (longueur du bloc avant)
lext = 15 mm | (longueur de l’extension)
lo = 33 mm | (distance boule bas - centre du cardan)
mstylet = 0.1 kg | (masse du stylet)
ltige = 0.2 m | (longueur du stylet)
cbas = 6 mm | (largeur extension bas)
r2 = 21 mm | (hauteur du bloc arrière)
L3 = 8 mm | (longueur entre centre cardan et centre boule m3)

### 3.5 Calcul d’erreur du aux accélération

### 3.5.1 Calcul d’erreur pour une accélération en z due à la non-linéarité de l’équilibrage

Au repos, le système est équilibré à 100% le point de départ du calcul des équilibrages dans la section précédente (somme des quantités de mouvement et des moments cinétiques nulles). Cependant, pour calculer l’éventuelle erreur maximale, le stylet a été déplacé de la distance maximale puis accélérer.

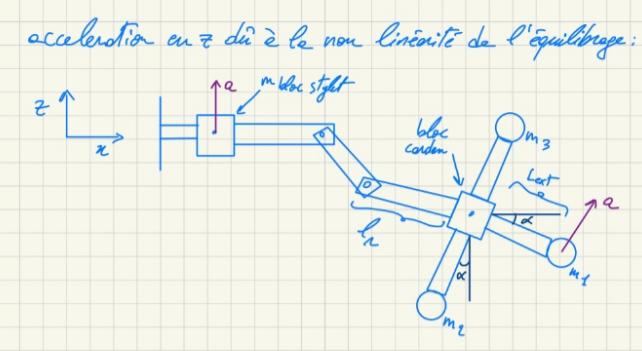
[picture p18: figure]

Figure 17 – Calcul d’erreur pour l’accélération en z

Force résiduelle :

F(α) = (mblocc + mtige)az − 2m1 cos(α) az

lext
lr

+ (m2 − m3) sin(α) az · 2l0/lr

Force résiduelle maximale :

max (|F(αmin)|, |F(αmax)|, |F(α0)|) pour α ∈ [αmin, αmax]

avec :
αmax = −αmin = arcsin

course max
Lr

= arcsin
7.5
≈ 7.6

◦

Ce alpha sera utilisé pour la suite des calculs.

et α0 tel que F

′
(α0) = 0 :

⇒ m1 sin(α)

lext
lo

+ (m2 − m3) cos(α) = 0

⇒ α0 = arcsin

−

lo(m2 − m3)

lext | !

application numerique :α0 = −14.07◦
en dehors du domaine, F(αmin) = −174mN,F(αmax) = 187mN. Origine de l’erreur : Les masses m2 et m3 sont trop lourdes, elles dominent sur le sin(alpha). Pour remédier à ce problème, une solution serait de faire en sorte que la rotation ry se fasse au niveau du centre du masse du stylet. De cette sorte, l’accélération ne sollicitera pas une différence de moment entre m2 et m3 et donc réduit considérablement l’erreur.

### 3.5.2 Calcul d’erreur pour l’accélération en y

La même démarche qu’avec z a été appliquée ici.

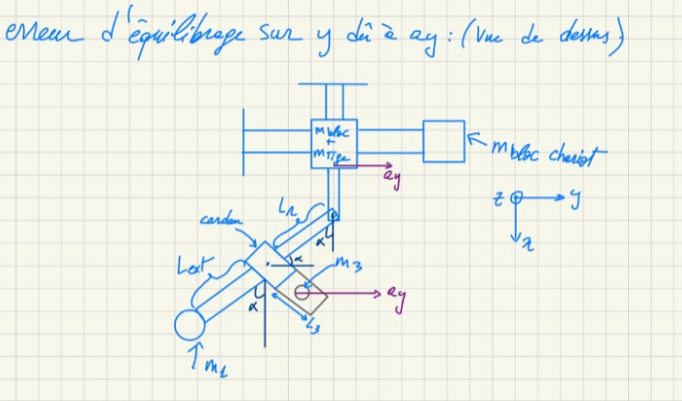
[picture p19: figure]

Figure 18 – Schéma calcul d’erreur selon y, vue du haut. La barre verticale à gauche et horizontale en haut est un symbole pour indiquer la symétrie

Force résiduelle :

Frésiduelle(α) = (mbloc + mtige)ay + 2(mbloc glissière)ay − 2

m1Lext + m1,extension

Lext
2
cos(α)ay/Lr

−2 (m3l3 + m3,extensionl3 · 0.5) sin(α)ay/Lr

avec :

m1,extension = ρ · Lext · c

2 = 0.42g et m3,extension = ρ · l0 · c

2
ext = 25g

mbloc glissière = ρ1 · cg · cl

- ch = 1,25 g

Force résiduelle maximale :

max (|F(−7.6)|, |F(7.6)|, |F(α0)|) avec F

′
(α0) = 0

⇒ (2m1Lext + 2m1,extension

Lext
2

) sin(α0) = 2 (m3l3 + m3,extensionl3 · 0.5) cos(α0)

⇒ α0 = tan⁻¹

m3l3 + m3,extension · 0.5l3 m1Lext + m2,extension · 0.5Lext !
= 0

Application Numérique : F(0) = 4.8mN, F(7.6

◦
) = 293mN, F(−7.6

◦
) = −270mN

Cette erreur est due à la distance entre la masse située en haut et le centre de rotation.

Solution qui aurait dû être implémentée : centrer la masse m3, située au-dessus du cardan, sur l’axe de rotation du cardan. Cela peut être réalisé en positionnant la lame verticalement, sur le côté du bloc, de manière à conserver le même comportement dynamique du cardan. Ceci revient à considérer l3 = 0, l’erreur devient alors 13 mN ce qui est conforme au cahier des charges.

Une telle configuration aurait également un effet sur la rigidité équivalente keq du système.

### 3.5.3 Erreur d’équilibrage liée à l’accélération en x

La même démarche a aussi été appliquée.

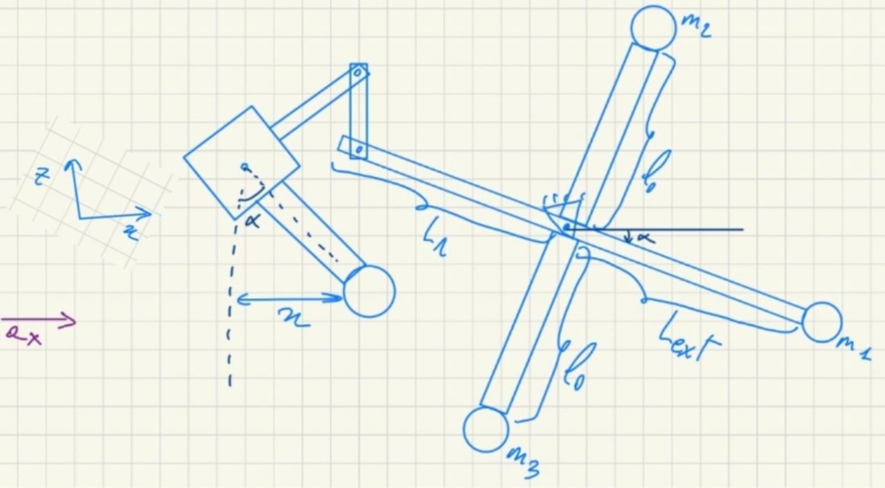
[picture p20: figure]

Figure 19 – Calcul d’erreur pour l’accélération en x

Malgré le fait que la translation en x soit bloquée, l’accélération en x génère un moment selon eˆy car le centre de masse du stylet n’est pas confondu avec le centre de rotation.

Erreur due à ax avec un déplacement x selon eˆx (on prend l’angle α = arctan
x

Lstylet
) :

Mrésiduel(α) = 2m1Lext sin(α)ax + 2(m3 − m2)l0 cos(α)ax −

mstylet

L
3

+

a
2

cos(α) · ax

= 2m1Lext sin(α) · ax (car m2 − m3 =

mstylet
L
3 +

a
2

2l0

)

Moment résiduelle maximale :

Mrésiduelle, max = 2m1Lext sin
sin⁻¹

course
Lr
·ax | ⇒ | Fmax = 2m1

Lext
Lr

×course·ax/Lstylet = 3.48mN

### 3.5.4 Erreur due à une accélération en rotation selon l’axe ry

D’après les calculs, le système est équilibré en moment autour de l’axe ry. Cependant, si une force est appliquée selon y en premier, l’orientation du cardan change légèrement selon une rotation autour de l’axe z. Cela entraîne un désalignement entre le moment cinétique des masses autour du cardan et celui du stylet, générant une différence de moment, et donc une erreur.

En considérant un déplacement maximal en y de 1 mm (égal à la course maximale), le cardan serait incliné d’un angle :
α = arcsin

1 mm
Lr
= arcsin

1
7,5

!
≈ 7,6

◦

avec Lr = 7,5 mm.

La différence de moment généré est alors :

∆M = M · (1 − cos α)

où M est le moment dû à l’accélération en rotation.

La force parasite induite peut être exprimée par :

Fparasite =

(Icardan + Istylet) · ω˙ · (1 − cos α)

Lstylet

avec les valeurs suivantes : — ω˙ = 30 rad/s²
: accélération angulaire,
— Lstylet = 200 mm,
— α = 7,6

◦
En appliquant ces valeurs numériques, on obtient :

Fparasite ≈ 1,35 mN

Cette force est donc bien inférieure au seuil acceptable de 15 mN.

### 3.6 Calcul de la masse réduite

Pour le calcul de la masse réduite, l’énergie cinétique d’une masse équivalente positionnée à l’extrémité du stylet est égale à l’énergie cinétique réelle du système.

1
2

meq,z · v

2 =

1
2

(mstylet + mbloc central) · v

2 + (Ibloc cardam + Im2,y + Im3,y) · ω

2
(9)

où v = Lr · ω.

meq,z = mstylet + mbloc central + 2 ·

Ibloc cardan + Im1,y + Im2,y + Im3,y
L²
r

(10)

En y, l’énergie cinétique équivalente est donnée par :

1
2

meq,y · v

2 =

1
2

(mstylet + mbloc central) · v

2 + (Icardan,z + Im1,z + Im2,z + Im3,z) · ω

2
(11)

On en déduit :

meq,y = mstylet + mbloc central +

2 · (Icardan,z + Im1,z + Im2,z + Im3,z)
L²
r

(12)

avec Lr =

v
ω

L’énergie cinétique équivalente en rotation autour de l’axe y est exprimée par :

1
2

Ieq,ry · ω

2 =

1
2

(Istylet,y + Ibloc central) · ω

2 + (Icardan,y + Im1,y + Im2,y + Im3,y) · ω

2
(13)

On obtient alors :

Ieq,ry = Istylet,y + Ibloc central + 2 · (Icardan,y + Im1,y + Im2,y + Im3,y) | (14)

Pour passer à la masse équivalente meq,ry, on utilise la relation :

meq,ry =

Ieq,ry · ω

2
v

2

avec v = (Lstylet +

a
2

) · ω

d’où :

meq,ry =

Istylet,y + Ibloc central + 2 · (Icardan,y + Im1,y + Im2,y + Im3,y)
Lstylet +

a
2

2

(15)

L’application numérique donne les valeurs suivantes des masses équivalentes :

meq,z = 18,044 kg, | meq,y = 3,37 kg, | meq,ry = 0,046 kg

Les masses équivalentes en z et y sont particulièrement élevées ce qui n’est pas idéal pour un palpage rapide. Cependant, l’équilibrage a été la prioriété lors de la conception du mécanisme comparé à la masse réduite.

## 4 Discussion

La discussion concernant le dimensionnement et les spécifications des accélératiosn est intégré dans la partie dimensionnement. Le sys

Pour les vitesses en rotation, vu que notre système n’est pas équilibré inertiellement, les forces d’inertie ne seraient pas annulées.

Concernant l’orientation de la gravité, qui est perçue comme une accélération en translation, le pire des cas correspond à une gravité orientée selon la direction y, car l’erreur générée dans cette situation est particulièrement importante.

Pour la non conformite au cahier de charge , le calcul du prix n’a pas ete pris en consideration vu que le prix du titane est d’environ 20 euros / kg et qu’avec le prix de conception du systeme, ce dernier n’arrivera pas aux 300 CHF fixes par la donnee.

## 5 Construction

### 5.1 Argumentation des choix de construction (procédé d’usinage et assemblages, etc.)

Les procédés d’usinage utilisés sont : le fraisage, le tournage, le taraudage et le filetage.

Fixation des vis

Un des blocs est taraudé, et l’autre est fraisé débouchant.

Un tube de titane est tourné de manière à obtenir le diamètre de la tige souhaitée d0, sauf aux extrémités :

— Une extrémité possède un diamètre plus grand (ce qui empêche la vis d’aller plus loin qu’il ne faut dans le bloc taraudé). Ensuite, ce diamètre est légèrement réduit (tout en restant supérieur à d0) et est fileté pour être vissé dans le bloc. Ce diamètre plus grand assure une meilleure fixation de la tige au bloc.
— L’autre extrémité de la tige possède également un diamètre supérieur à d0 et traverse le second bloc. La partie qui dépasse est filetée et fixée au bloc à l’aide d’un écrou.

Fixation des lames

La méthode choisie est le pressage des lames contre les blocs.

Cas 1 : fixation d’une lame à un bloc.
— Le bloc est taraudé.
— La lame est percée à l’extrémité avec un trou de même diamètre que le taraudage. — Un bloc percé avec le même trou est placé par-dessus la lame.
— Enfin, une vis serre l’ensemble.
Cas 2 : fixation de deux lames à un bloc.
— Les deux lames, déjà percées, sont positionnées sur un bloc.
— Deux blocs (l’un taraudé, l’autre non) sont placés au-dessus et en dessous des lames. — Une vis serre l’ensemble de manière rigide.

Usinage des blocs

Les blocs sont fraisés pour obtenir les dimensions souhaitées. Pour le taraudage :
— Le bloc est d’abord percé avec un diamètre légèrement inférieur à celui du filetage. — Ensuite, le filetage est réalisé à l’aide d’un taraud.

### 5.2 Argumentation des choix des matériaux

Dans la partie 3 (Dimensionnements), il a été démontré que le titane présente une résistance largement suffisante au flambage dans le cadre du mécanisme étudié.

Il est désormais nécessaire d’évaluer sa résistance en fatigue.

Le cahier des charges secondaires impose une durée de vie minimale de 10 ans, avec des cadences de palpage de 2 Hz, sur une durée d’utilisation quotidienne de 4 heures.

Sachant qu’une année comporte 31 536 000 secondes, une utilisation de 4 heures par jour correspond à :

31 536 000 ×

4
24
= 5 256 000 secondes par an | ⇒ | 52 560 000 secondes sur 10 ans.

Avec une fréquence de fonctionnement de 2 Hz, le nombre total de cycles sur 10 ans est estimé à :

2 × 52 560 000 = 1,05 × 10⁸ cycles.

Pour estimer la contrainte maximale admissible pour 1,05 × 10⁸
cycles, l’article “The Very High Cycle Fatigue Behavior of Ti-6Al-4V Alloy”, publié dans Acta Physica Polonica Series A, fournit une courbe S-N qui permet une extrapolation raisonnable :

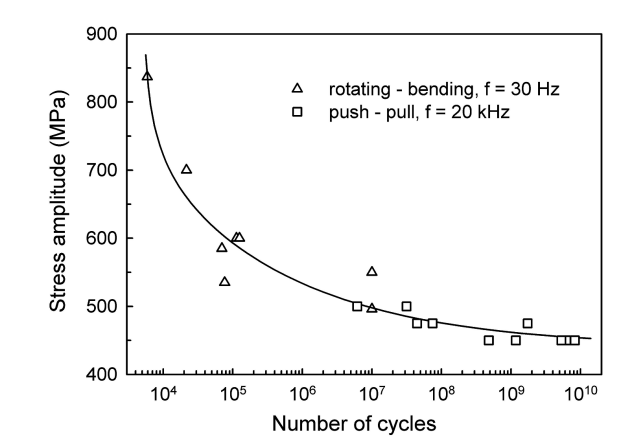
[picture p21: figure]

Figure 20 – systeme d’equilibrage sans les masses verticales

D’après cette source, la contrainte maximale supportée à 10⁸
cycles, dans le cas d’un essai en traction-compression à 20 kHz, est d’environ 480 MPa.

La contrainte maximale appliquée dans le système analysé étant d’environ 500 MPa, et la fréquence de fonctionnement réelle (2 Hz) étant très inférieure à celle des essais (20 kHz), il est raisonnable de conclure que la durée de vie exigée par le cahier des charges est respectée avec les lames et tiges fabriquées en Titane.

Pour les blocs rigides, l’acier Böhler a été sélectionné en raison de sa haute rigidité, avec un module d’élasticité E = 196 GPa.

## 6 Conclusion

Ce projet a représenté une expérience à la fois exigeante et enrichissante dans le domaine de l’ingé-nierie. Tout au long de son déroulement, nous avons été confrontés à divers défis que nous avons dû surmonter afin de respecter les consignes et les contraintes imposées. Ces difficultés nous ont poussés à approfondir nos raisonnements et à développer nos compétences dans plusieurs domaines, tout en acquérant une précieuse expérience pratique. Les séances de soutien hebdomadaires de 45 minutes se sont révélées très utiles. Ce projet nous a ainsi permis de nous familiariser avec un rythme de travail structuré, une communication efficace en équipe, et une gestion de projet réaliste, autant d’éléments qui constituent une préparation concrète et précieuse à notre future vie professionnelle.

## 7 Annexes

Dessin de construction avec liste de toutes les pièces

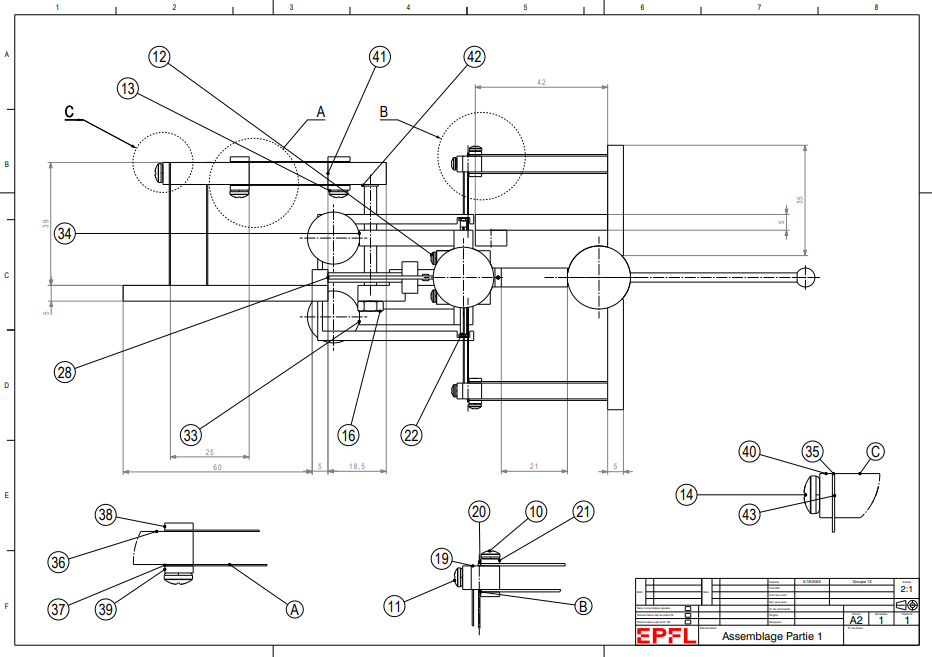
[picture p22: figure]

Figure 21

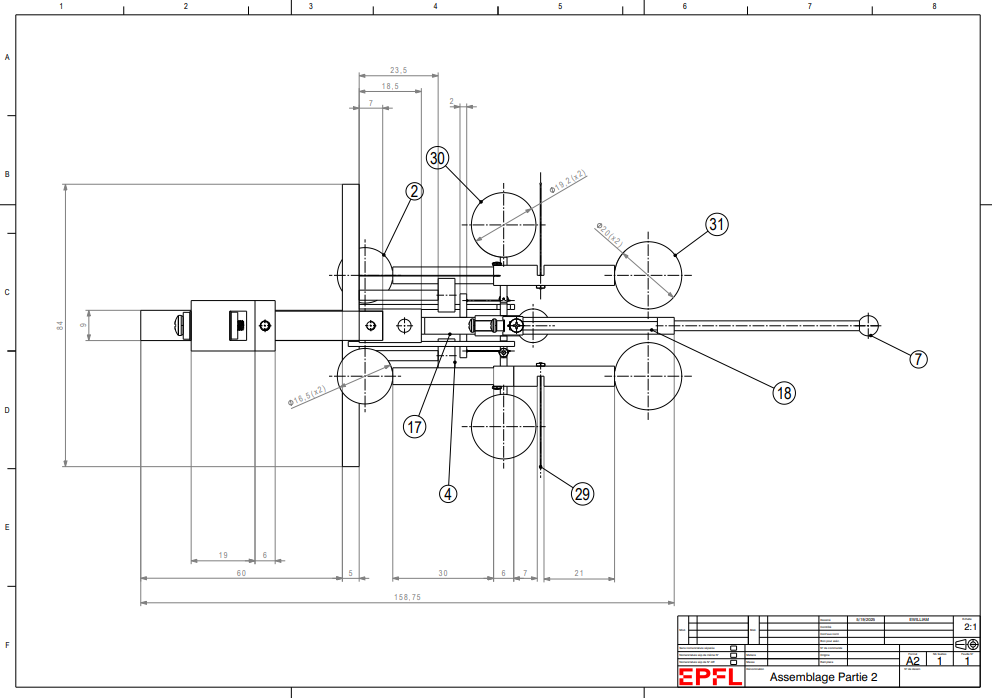
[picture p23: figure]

Figure 22

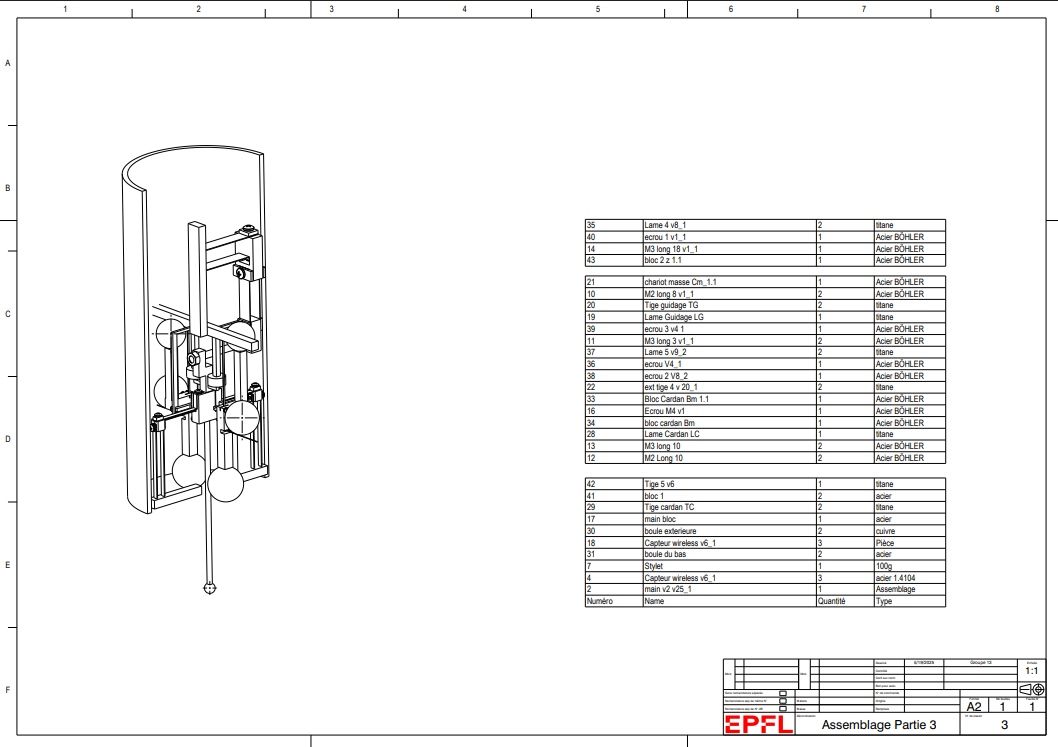
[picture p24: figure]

Figure 23

## Code Python utilisé pour le dimensionnement

Voici le script Python utilisé pour le calcul des constantes de rigidité, contraintes et flambage :

[fontsize=, linenos, frame=lines, bgcolor=gray !5]python import math import numpy as np import matplotlib.pyplot
as plt

Constantes globales sigmaadm = (500e6/3)P aLr = 7.5E−3Longueurderéférence(m)R1 = 1E−3Distancerelative(m)Rp = 0.22RapportR2 = 21E − 3b = 6e − 3

Classe de base class Element : def init(
self,L,E,G):self.L=Lself.Iy=Nonerigiditésself.KalphaM=Noneself.Kf M=Noneself.KalphaP =Noneself.Kf P =Noneself.Ktors=Nonecoursesadmissiblesself.alphaf m=Noneself.ff
def computef lexionK(self) : EIy = self.E ∗ self.Iyself.KalphaM = 4 ∗ EIy ∗ (self.L ∗ ∗2 + 3 ∗ b/2 ∗ self.L + 3/4 ∗ b ∗ ∗2)/self.L ∗ ∗3self.KfM = 4 ∗ EIy/self.Lself.KalphaP = 2 ∗ EIy/self.L ∗ ∗2self.KfP = 12 ∗ EIy/self.L ∗ ∗3

def verifycoursealphafm(self, course) : returncourse < self.alphafm

def verifycoursef f f(self, course) : returncourse < self.ff f

def verifycoursealphat(self, course) : returncourse < self.alphat

Lame rectangulaire class Lame(Element) : def init(
self,L,b,h,E,G):super().
init
(L,E,G)self.b,self.h=b,hself.Iy=b∗h∗∗3/12self.computef

lexionK()self.Ktors=b∗h∗∗3∗self.G/(3∗L)self.computemaxcourse()self.E=Eself.G=Gself.A=self.b∗self.h
def computemaxcourse(self) : self.alphafm = (2 ∗ sigmaadm ∗ self.L)/(self.E ∗ self.h)self.ff f = (2 ∗ sigmaadm ∗ self.L ∗ ∗2)/(3 ∗ self.E ∗ self.h)self.alphat = (sigmaadm ∗ self.L)/(self.h ∗ self.G)self.Kinter = self.E ∗ self.h ∗ self.b ∗ ∗3/self.L ∗ ∗3

Tige circulaire class Tige(Element) : def init(
self,L,d,E,G):super().
init
(L,E,G)self.d=dself.Iy=math.pi∗d∗∗4/64self.computef

lexionK()self.Ktors=math.pi∗self.G∗d∗∗4/(32∗L)self.computemaxcourse()self.E=Eself.G=Gself.A=math.pi∗self.d∗∗2/4
def computemaxcourse(self) : self.alphafm = (2 ∗ sigmaadm ∗ self.L)/(self.E ∗ self.d)self.ff f = (2 ∗ sigmaadm ∗ self.L ∗ ∗2)/(3 ∗ self.E ∗ self.d)self.alphat = (2 ∗ sigmaadm ∗ self.L)/(self.d ∗ self.G)

Fonctions de vérification globales def verifyy(l1, l2, t1, t2, course) : return(l1.verifycoursef f f(course)andl2.verifycoursealphat(course/Lr)andt1.verifycoursealphat(course/Lr)andt2.verifycoursealphafm(course/Lr))

def verifyry(l2, l3, t2, t3, t4, course) : return(l2.verifycoursealphafm(course/Lr)andl3.verifycoursealphat(course/Lr)andt3.verifycoursef f f(course/(Lr∗ R1))andt2.verifycoursealphafm(course/Lr)andt3.verifycoursealphat(course/Lr)andt4.verifycoursealphat(2∗course/Lr))

Instanciation des éléments l1 = Lame(L=40E-3, b=2.5E-3, h=0.5E-3,E =114E9,G=41E9) l2 = Lame(L=40E-3, b=1E-3, h=0.2E-3,E =114E9,G=41E9) l3 = Lame(L=25E-3, b=3E-3, h=0.3E-3,E =114E9,G=41E9) l4 = Lame(L=32e-3,
b=8.6E-3, h=0.36E-3,E =114E9,G=41E9) l5 = Lame(L=25e-3, b=8.7E-3, h=0.28E-3,E =114E9,G=41E9)

t1 = Tige(L=10E-3, d=0.3E-3,E =114E9,G=41E9) t2 = Tige(L=27E-3, d=0.121E-3,E =114E9,G=41E9) t3 = Tige(L=25E-3, d=0.3E-3,E =114E9,G=41E9) t4 = Tige(L=15E-3, d=0.5E-3,E =114E9,G=41E9) t5 = Tige(L=32e-3, d=3.9e-3,E =114E9,G=41E9)

course = 1E-3

print("Calcul de force de rappel") Frappel = course * l1.KfP F critiqueL3 = (math.pi) ∗ ∗2 ∗ l3.E ∗ l3.Iy/(0.5 ∗ l3.L) ∗
∗2F critiquet3 = (math.pi) ∗ ∗2 ∗ t3.E ∗ t3.Iy/(0.5 ∗ t3.L) ∗ ∗2sigmacompressiont1 = (t2.KalphaM + l2.KalphaM) ∗ math.asin(course/Lr)/Lr/(math.pi∗t1.d∗∗2/4)print(f”sigmacrsigmacompressiont1 : .2f”)print(f”RappelF rappel : .2fN, F crL3F critiqueL3 : .2fN, F crT3F critiquet3 : .2fN”)

Calculs des keq keqz = 2∗(l3.KfP +t3.KfP +l4.KfP ∗t5.KfP/(2∗l4.KfP +t5.KfP)+(l2.KalphaM +t2.KalphaM +
t4.Ktors)/(Lr ∗ ∗2))

keqy = (4 ∗ l1.KfP + 2 ∗ l5.KfP + 2 ∗ (l2.Ktors + t2.KalphaM + t1.Ktors)/(Lr ∗ ∗2))

keqry = (2 ∗ (l2.KalphaM + l3.Ktors + t3.Ktors + t3.KfP ∗ R1 ∗ ∗2 + t2.KalphaM + 4 ∗ t4.Ktors) + R2 ∗ ∗2 ∗ t5.KfP + t5.Ktors)/Rp ∗ ∗2

Réajustement de la course si keq trop petit if keqy < 5andkeqz < 5 : course = 5/min(keqy, keqz)

print(f"keqz = keqz : .4f”)print(f”keqy = keqy : .4f”)print(f”keqry = keqry : .4f”)print(f”course = course : .4f”)print(f”verifyy = verifyy(l1, l2, t1, t2, course)”)print(f”verifyry = verifyry(l2, l3, t2, t3, t4, course)”)

Affichage des contributions corrigé datasets = ’keq′
z

:

′

labels′

: [′
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
l4//l5)′
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
′ keq′
z

],

′

contribs′
: [2 ∗ (l3.KfP), 2 ∗ t3.KfP, 2 ∗ (l4.KfP ∗ t5.KfP/(2 ∗ l4.KfP + t5.KfP)), l2.KalphaM/Lr ∗ ∗2, t2.KalphaM/Lr ∗ ∗2, t4.Ktors/Lr ∗ ∗2, keqz, ],
′

labels′

: [′
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
′ keq′
y

],

′

contribs′
: [4 ∗ l1.KfP, 2 ∗ l5.KfP, 2 ∗ (l2.Ktors/Lr ∗ ∗2), 2 ∗ (t2.KalphaM/Lr ∗ ∗2), 2 ∗ (t1.Ktors/Lr ∗ ∗2), keqy, ],
′

labels′

: [′
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
t3tors′
,

′

t3f lex′
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
t5f lex′
,

′

t5tors′
,

′ keqry

′
],

′

contribs′
: [2 ∗ l2.KalphaM/Rp ∗ ∗2, 2 ∗ (l3.Ktors)/Rp ∗ ∗2, 2 ∗ t3.Ktors/Rp ∗ ∗2, 2 ∗ (t3.KfP ∗ R1 ∗ ∗2)/Rp ∗ ∗2, 2 ∗ t2.KalphaM/Rp ∗ ∗2, 2 ∗ (4 ∗ t4.Ktors)/Rp ∗ ∗2,(R2 ∗ ∗2 ∗ t5.KfP)/Rp ∗ ∗2, t5.Ktors/Rp ∗ ∗2, keqry, ],

print(f" l4.KfP ∗ t5.KfP/(2 ∗ l4.KfP +t5.KfP) = l4.KfP ∗ t5.KfP/(2 ∗ l4.KfP + t5.KfP) : .4f”)print(f”t5.KfP = t5.KfP : .4f”)print(f”l4.KfP = l4.KfP : .4f”)

for keqname, dataindatasets.items() : print(f”forkeqname : ”)forlabel, contribinzip(data[

′

labels′
], data[

′

contribs′
]) :
print(f”label− > contrib”)print(f”T otalkeqname : data[

′

total′
]”)

for name, data in datasets.items() : labels = data[’labels’] vals = np.array(data[’contribs’]) total = data[’total’] pct = 100 * vals / total

x = np.arange(len(labels)) width = 0.35

fig, ax1 = plt.subplots(figsize=(8,4)) ax2 = ax1.twinx()

histogrammes ax1.bar(x - width/2, vals, width, color=’green’, label=’K valeurs’) ax2.bar(x + width/2, pct, width, color=’yellow’, label=’

bornes critiques ax1.axhline(4500, color=’red’, linestyle=’–’) ax1.axhline(5500, color=’red’, linestyle=’–’) ligne du keq ax1.axhline(total, color=’black’, linestyle=’-’, label=f’keq = total :.2f’)

ax1.setxticks(x)ax1.setxticklabels(labels, rotation = 45, ha =′

right′
)ax1.setylabel(

′K(N/m)

′
)ax2.setylabel(

′ax1.settitle(f

′Contributionsauname′

légende combinée m1, n1 = ax1.getlegendhandleslabels()m2, n2 = ax2.getlegendhandleslabels()ax1.legend(m1 + m2, n1 + n2, loc =′ upperlef t′
)

plt.tightlayout()plt.show(),

→ Z az = math.asin(course / Lr) stressz = ′

labels′

: [′
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
′ values′
: [sigmacompressiont1, t2.E ∗ (2 ∗ t2.d ∗ t2.L + 3/2 ∗ b ∗ t2.d) ∗ az/t2.L ∗ ∗2, tige2course ∗ t3.E ∗ t3.d ∗ 3/(t3.L ∗ ∗2), tige3math.sqrt(3) ∗ az ∗ t4.G ∗ t4.d/(2 ∗ t4.L), tige42 ∗ l4.KfP ∗ course/t5.A,(l3.KfP + t3.KfP) ∗ course/(2 ∗ l1.A), lame1l2.E ∗ (2 ∗ l2.h ∗ l2.L + 3/2 ∗ b ∗ l2.h) ∗ az/l2.L ∗ ∗2, lame23 ∗ l3.E ∗ l3.h ∗ course/(l3.L ∗ ∗2), lame33 ∗ l4.E ∗ l4.h ∗ course/(l4.L ∗ ∗2), lame42 ∗ l4.KfP ∗ t5.KfP/(2 ∗ l4.KfP + t5.KfP) ∗ course/(2 ∗ l5.A), lame5

]

→ Y ay = math.asin(course / Lr) stressy = ′

labels′

: [′
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
′ values′
: [math.sqrt(3) ∗ ay ∗ t1.G ∗ t1.d/(2 ∗ t1.L), tige1t2.E ∗ (2 ∗ t2.d ∗ t2.L + 3/2 ∗ b ∗ t2.d) ∗ ay/t2.L ∗ ∗2, tige22 ∗ l1.KfP ∗ course/t3.A, tige34 ∗ (l2.Ktors + t2.KalphaM) ∗ ay/(math.pi ∗ (t4.d ∗ ∗2) ∗ Lr), tige42 ∗ l5.KfP ∗ course/(t5.A), tige53 ∗ l1.E ∗ l1.h ∗ course/(l1.L ∗ ∗2), lame1math.sqrt(3) ∗ l2.G ∗ l2.h ∗ ay/l2.L, lame22 ∗ l1.KfP ∗ course/l3.A, lame3l5.KfP ∗ course/(l4.A), lame43 ∗ l5.E ∗ l5.h ∗ course/(l5.L ∗ ∗2), lame5]

→ RY ar = math.asin(course / Rp) stressry = ′

labels′

: [′
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
l4cisinter′
,

′

l5cisinter′
],

′ values′
: [(l2.KalphaM + t2.KalphaM) ∗ ar/Lr/t1.A, t2.E ∗ (2 ∗ t2.d ∗ t2.L + 3/2 ∗ b ∗ t2.d) ∗ ar/t2.L ∗ ∗2, tige2(math.sqrt(3) ∗ ar ∗ t2.G ∗ t3.d/(2 ∗ t3.L) + R1 ∗ ar ∗ 3 ∗ t3.E ∗ t3.d/(t3.L ∗ ∗2)), tige3math.sqrt(3) ∗ ar ∗ t4.G ∗ t4.d/t4.L, tige4math.sqrt(3) ∗ ar ∗ t5.G ∗ t5.d/(2 ∗ t5.L) + R2 ∗ ar ∗ 3 ∗ t5.E ∗ t5.d/(t5.L ∗ ∗2), tige53 ∗ (l3.Ktors ∗ ar + t3.KfP ∗ R2 ∗ ∗2 ∗ ar)/(l1.h ∗ l1.b ∗ ∗3), lame1l2.E ∗ (2 ∗ l2.h ∗ l2.L + 3/2 ∗ b ∗ l2.h) ∗ ar/l2.L ∗ ∗2, lame2math.sqrt(3) ∗ ar ∗ l3.G ∗ l3.h/(l3.L), lame33 ∗ t5.KfP ∗ ar ∗ R2 ∗ l4.L/(l4.h ∗ l4.b ∗ ∗2), lame43 ∗ t5.KfP ∗ ar ∗ R2 ∗ l5.L/(l5.h ∗ l5.b ∗ ∗2), lame5]

Affichage console for name, data in [(’Z’, stressz),(

′Y

′
, stressy),(

′RY ′
, stressry)] : print(f”pourname : ”)forlbl, valinzip(data[

′

labels′
print(f”lbl :> 2− > val :> 10.2fP a”)

Fonction de tracé def plotstress(data, title) : x = np.arange(len(data[

′

labels′
]))values = np.array(data[

′values′
])f ig, ax =
plt.subplots(f igsize = (8, 4))ax.bar(x, values)ax.axhline(sigmaadm, linestyle =′ −−′ , label = f

′

adm = sigmaadm : .0fP a′
)ax.setxticks(x)ax.setxticklabels(data[ 45, ha =′

right′
)ax.setylabel(

′Contrainte(P a)

′
)ax.settitle(f

′Contrainteentitle′
)ax.legend()plt.tightlayout()plt.show()

Tracés finaux plotstress(stressz,

′ Z

′
)plotstress(stressy,

′ Y

′

)plotstress(stressry,′ RY ′ )

print("Calcul de force de rappel pour le mouvement en z") sigmacompressiont1z = (t2.KalphaM + l2.KalphaM) ∗
math.asin(course/Lr)/Lr/(math.pi∗t1.d∗∗2/4)sigmacompressionl1 = (l3.KfP+t3.KfP)∗course/(2∗l1.A)sigmacompressionl5 = 2∗l4.KfP∗t5.KfP/(2∗l4.KfP+t5.KfP)∗course/(2∗l5.A)print(f”Compt1sigmacompressiont1z : .2fP a, Compl1sigmacompressionl1 : .2fP a, Compl5sigmacompressionl5 : .2fP a”)sigmaf lambaget1z = math.pi ∗ ∗2 ∗ t1.E ∗ t1.Iy/(t1.A ∗ (t1.L/2) ∗ ∗2)sigmaf lambagel1 = math.pi ∗ ∗2 ∗ l1.E ∗ l1.Iy/(l1.A ∗ (l1.L/2) ∗
∗2)sigmaf lambagel5 = math.pi∗∗2∗l5.E∗l5.Iy/(l5.A∗(l5.L/2)∗∗2)print(f”Sigmacrt1sigmaf lambaget1z : .2fP a, Sigmacrl1sigmaf lambagel1 : .2fP a, Sigmacrl5sigmaf lambagel5 : .2fP a”)

print("Calcul de force de rappel pour le mouvement en y") sigmacompressiont3 = 2∗l1.KfP∗course/t3.Asigmacompressiont4 =
(l2.Ktors+t2.KalphaM) ∗ ay/(t4.A∗Lr)sigmacompressiont5 = 2 ∗ l5.KfP ∗ course/(t5.A)sigmacompressionl3 = 2 ∗
l1.KfP∗course/l3.Asigmacompressionl4 = l5.KfP∗course/(l4.A)print(f”Compt3sigmacompressiont3 : .2fP a, Compt4sigmacompressiont4 : .2fP a, Compt5sigmacompressiont5 : .2fP a, Compl3sigmacompressionl3 : .2fP a, Compl4sigmacompressionl4 : .2fP a”)sigmaf lambaget3 = math.pi ∗ ∗2 ∗ t3.E ∗ t3.Iy/(t3.A ∗ (t3.L/2) ∗ ∗2)sigmaf lambaget4 = math.pi ∗ ∗2 ∗ t4.E ∗ t4.Iy/(t4.A ∗ (t4.L/2) ∗
∗2)sigmaf lambaget5 = math.pi ∗ ∗2 ∗ t5.E ∗ t5.Iy/(t5.A ∗ (t5.L/2) ∗ ∗2)sigmaf lambagel3 = math.pi ∗ ∗2 ∗ l3.E ∗
l3.Iy/(l3.A∗(l3.L/2)∗∗2)sigmaf lambagel4 = math.pi∗∗2∗l4.E∗l4.Iy/(l4.A∗(l4.L/2)∗∗2)print(f”Sigmacrt3sigmaf lambaget3 : .2fP a, Sigmacrt4sigmaf lambaget4 : .2fP a, Sigmacrt5sigmaf lambaget5 : .2fP a, Sigmacrl3sigmaf lambagel3 : .2fP a, Sigmacrl4sigmaf lambagel4 : .2fP a”)

print("Calcul de force de rappel pour le mouvement en ry") sigmacompressiont1ry = (l2.KalphaM + t2.KalphaM) ∗
ar/Lr/t1.Aprint(f”Compt1sigmacompressiont1ry : .2fP a”)sigmaf lambaget1ry = math.pi ∗ ∗2 ∗ t1.E ∗ t1.Iy/(t1.A∗
(t1.L/2) ∗ ∗2)print(f”Sigmacrt1sigmaf lambaget1ry : .2fP a”)

import numpy as np import matplotlib.pyplot as plt from matplotlib.patches import Patch

(Re)définissez ici vos listes si besoin : labels = [ ’t1 (z)’, ’l1 (z)’, ’l5 (z)’, ’t3 (y)’, ’t4 (y)’, ’t5 (y)’, ’l3 (y)’, ’l4 (y)’, ’t1 (ry)’ ]
compvalues = [sigmacompressiont1z, sigmacompressionl1, sigmacompressionl5, sigmacompressiont3, sigmacompressiont4, sigmacompressiont5, sigmacompressionl3, sigmacompressionl4, sigmacompressiont1ry]buckvalues = [sigmaf lambaget1z, sigmaf lambagel1, sigmaf lambagel5, sigmaf lambaget3, sigmaf lambaget4, sigmaf lambaget5, sigmaf lambagel3, sigmaf lambagel4, sigmaf lambaget1ry]colors =
′
z

′
:

′

blue′
,

′ y

′
:

′

green′
,

′

ry′
:

′

red′
barcolors = [colors[

′
z

′
], colors[

′
z

′
], colors[

′
z

′
], colors[

′y

′
], colors[

′y

′
], colors[

′y

′
], colors[

′y

′
], colors[
0.35

— 1) Graphique échelle LINÉAIRE — figlin, axlin = plt.subplots(f igsize = (8, 4))x = np.arange(len(labels))foriinrange(len(labels)) : axlin.bar(x[i]−width/2, compvalues[i], width, color = barcolors[i])axlin.bar(x[i]+width/2, buckvalues[i], width, color =
barcolors[i], alpha = 0.3)

axlin.setxticks(x)axlin.setxticklabels(labels, rotation = 45, ha =′

right′
)axlin.setylabel(

′Contrainte(P a)

′
)axlin.settitle(”CompressionvsFlambagecritique(échellelinéaire)”)legendelems = [P atch(f acecolor =′

blue′

, label =′ Comp./tra.(z)

′

), P atch(f acecolor =′

blue′

, alpha = 0.3, label =′ Flamb.crit.(z)

′

), P atch(f acecolor =′
green′

, label =′ Comp./tra.(y)

′

), P atch(f acecolor =′

green′

, alpha = 0.3, label =′ Flamb.crit.(y)

′

), P atch(f acecolor =′
red′

, label =′ Comp./tra.(ry)

′

), P atch(f acecolor =′

red′

, alpha = 0.3, label =′ Flamb.crit.(ry)

′
)]axlin.legend(handles =
legendelems)plt.tightlayout()

— 2) Graphique échelle LOGARITHMIQUE — On prend log10 pour chaque liste : logcomp = np.log10(compvalues)logbuck = np.log10(buckvalues)

figlog, axlog = plt.subplots(f igsize = (8, 4))foriinrange(len(labels)) : axlog.bar(x[i]−width/2, logcomp[i], width, color = barcolors[i])axlog.bar(x[i] + width/2, logbuck[i], width, color = barcolors[i], alpha = 0.3)

axlog.setxticks(x)axlog.setxticklabels(labels, rotation = 45, ha =′

right′
)axlog.setylabel(

′
log10(Contrainte)[P a]

′
)axlog.settitle(”CompressionvsFlambagecritique(échellelog10)”)axlog.legend(handles = legendelems)plt.tightlayout()

plt.show()

contributiont1 = 2 ∗ (Lr ∗ (1 − math.cos(math.asin(course/Lr)))/course) ∗ ∗2 ∗ t1.KfP print(contributiont1)

contributionL1 = 4 ∗ ((t3.L − math.sqrt(t3.L ∗ ∗2 − course ∗ ∗2))/course) ∗ ∗2 ∗ l1.KfP print(contributionL1)

contributiont4 = 2 ∗ (Lr ∗ (1 − math.cos(math.asin(course/Lr)))/course) ∗ ∗2 ∗ t4.KfP print(contributiont4)

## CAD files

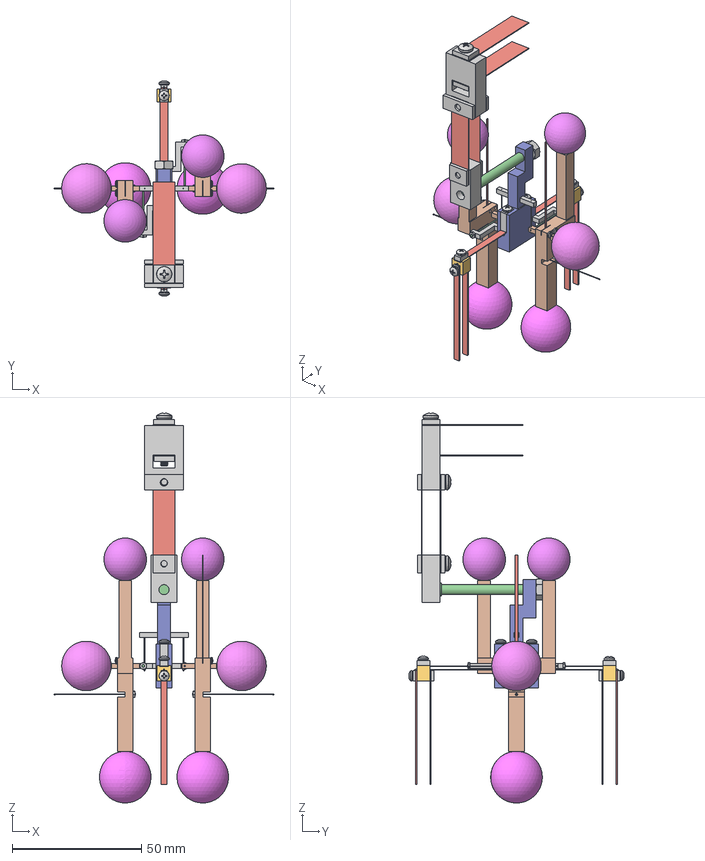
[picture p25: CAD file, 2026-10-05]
main v2.step
85.0 x 83.3 x 150.8 mm
Lame Base LB x 4
Lame Guidage LG x 2
Tige Guidage TG x 2
ext tige 4 x 2
Tige Verticale TV x 2
extension ext tige 1 x 2
Tige Horizontale TH x 2
Lame Cardan LC x 2
Tige Cardan TC x 2
Boule exterieur x 2
Boule du bas x 2
Boule du haut x 2
91800A034_18-8 Stainless Steel Narrow Cheese Head Slotted Screws x 4
Lame 4 x 2
Ecrou
Lame 5 x 2
Ecrou 2
ecrou 3
ecrou 1
Bloc 1 z
Tige 5
92000A015_Passivated 18-8 Stainless Steel Pan Head Phillips Screws x 2
92000A010_Passivated 18-8 Stainless Steel Pan Head Phillips Screws x 2
92000A017_Passivated 18-8 Stainless Steel Pan Head Phillips Screws x 2
92000A120_Passivated 18-8 Stainless Steel Pan Head Phillips Screws x 2
92000A127_Passivated 18-8 Stainless Steel Pan Head Phillips Screws
91828A003_18-8 Stainless Steel Hex Nut x 4
90591A255_Zinc-Plated Steel Hex Nut
